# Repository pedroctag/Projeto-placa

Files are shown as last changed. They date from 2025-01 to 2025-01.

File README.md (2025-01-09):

# PBLE02 - Gerenciamento de alarme

Este projeto foi feito por [Lucas Moura](https://github.com/lucaslpmoura), [Lucas Romualdo](https://github.com/ROMUALDO-TXT) e [Pedro Coelho Tagliaferro](https://github.com/pedroctag) para a disciplina PBLE02 - *Board Bring-up e Validação de Projetos*, na Universidade de Federal de Itajubá, em 2023/1.

O projeto consiste em um mockup de sistema de validação de alarmes, utilizando o microprocessador PIC18F4550 como base. 

## Dependências 
- [Kicad](https://www.kicad.org)
- [xc8](https://www.microchip.com/en-us/tools-resources/develop/mplab-xc-compilers)

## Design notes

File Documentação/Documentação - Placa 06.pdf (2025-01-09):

PBLE02

Board Bring-Up e Validação de Protótipos

Documentação de Hardware/Software

Grupo 06

### 1. IDENTIFICAÇÃO DOS INTEGRANTES

Lucas Louzada Paganoto Moura – 2022006102

Lucas Romualdo Lemos – 2021017077

Pedro Coelho Talgiaferro – 2021007929

## SUMÁRIO

### 2. INTRODUÇÃO

O objetivo deste projeto foi a aplicação componentes de hardware e o

desenvolvimento de software para uma placa de circuito impresso

desenvolvida por alunos da disciplina PBLE01.

A placa constitui um mockup de um sistema de gerenciamento de

alarme. O usuário pode definir os níveis de alarmes a serem gerenciados, e

a placa alerta quando os limiares previamente escolhidos são atingidos.

Para o hardware, foi seguido os esquemáticos e componentes

especificados pelo projeto inicial, porém alterações tiveram de ser feitas

devido a limitações na disponibilidade de componentes e erros de projeto.

O software foi desenvolvido na linguagem C, utilizando o compilador

XC8. Foram desenvolvidas bibliotecas próprias a fim de se obter o resultado

esperado, em conjunto com outras fornecidas pelo Profº. Rodrigo Almeida.

A seguir serão descritas a mudanças em hardware realizadas, o digrama

UML das bibliotecas criadas e o diagrama de estados utilizado pela lógica

interna da placa

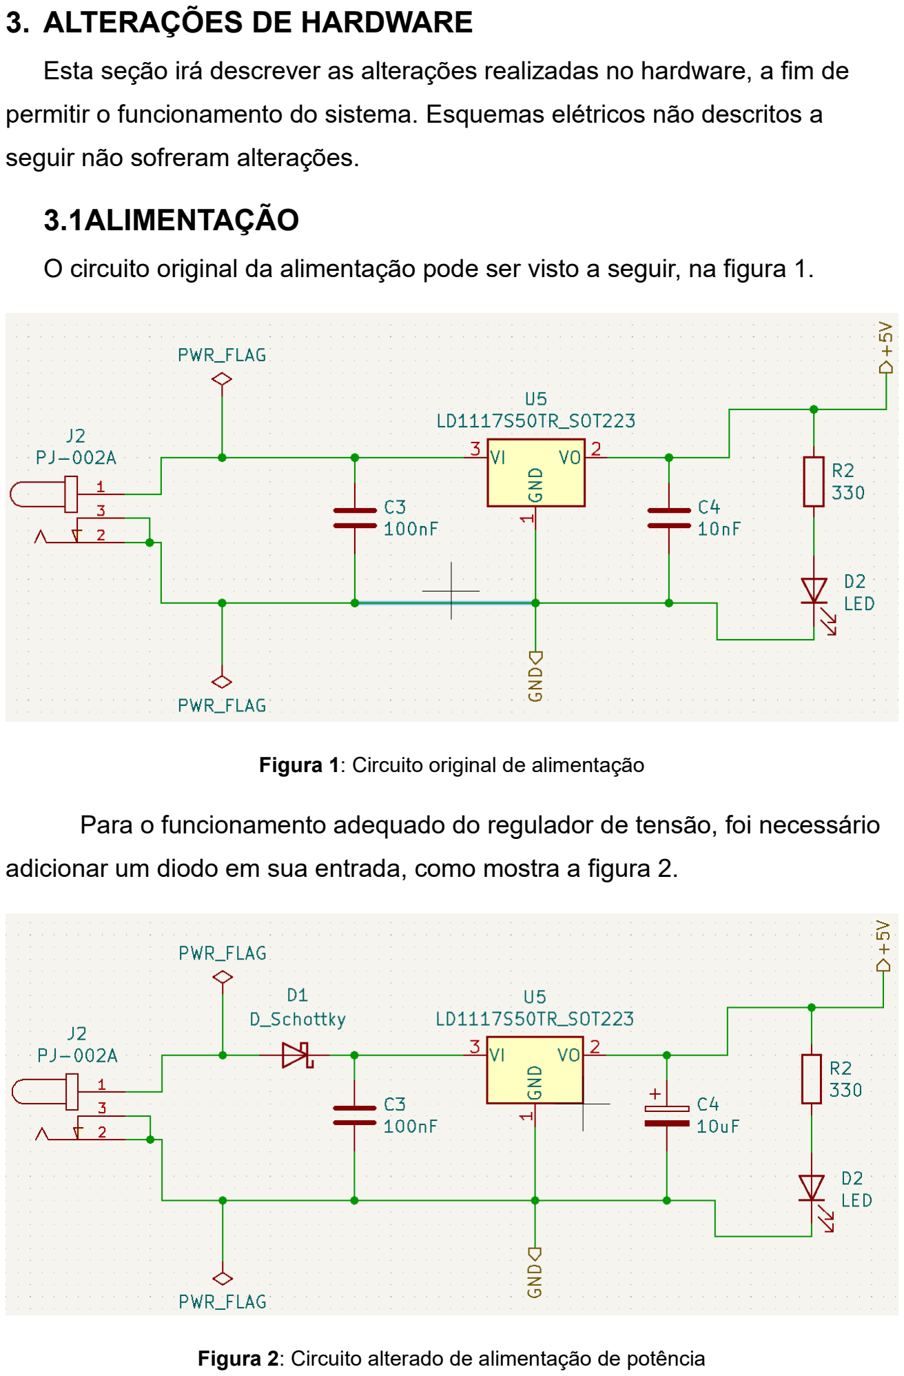
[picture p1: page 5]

### 3. ALTERAÇÕES DE HARDWARE

Esta seção irá descrever as alterações realizadas no hardware, a fim de

permitir o funcionamento do sistema. Esquemas elétricos não descritos a

seguir não sofreram alterações.

3.1ALIMENTAÇÃO

O circuito original da alimentação pode ser visto a seguir, na figura 1.

Figura 1: Circuito original de alimentação

Para o funcionamento adequado do regulador de tensão, foi necessário

adicionar um diodo em sua entrada, como mostra a figura 2.

Figura 2: Circuito alterado de alimentação de potência

### 3.2 LEDs DE SINALIZAÇÃO

O esquemático original dos leds pode ser visto a seguir, na figura 3.

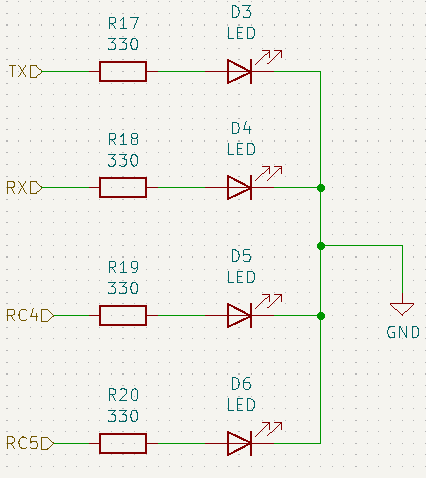
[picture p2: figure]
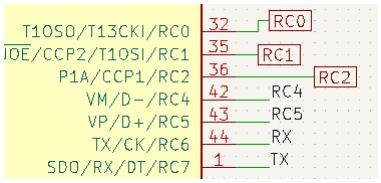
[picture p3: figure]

Figura 3: Leds sinalizadores e seus pinos conectados originalmente

Os pinos escolhidos originalmente para os leds sinalizadores (conexões

RC4 e RC5 nos pinos 42 e 43) só podem operar como entradas digitais. Na

configuração de catodo comum, os leds não conseguem operar. Assim optou-

se por trocar os pinos dos leds para 35 e 36, como mostra a figura 4.

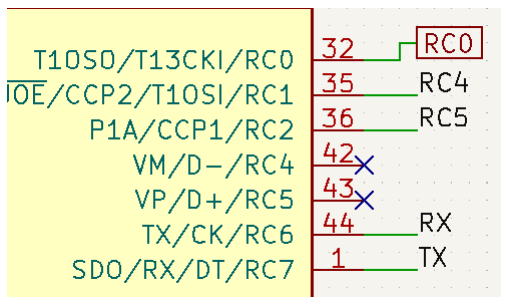
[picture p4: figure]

Figura 4: Pinagem atualizada dos leds

### 3.3 SAÍDA ANALÓGICA

No projeto original, a saída original possuía um filtro passa-baixa

simples, como mostra a figura 5.

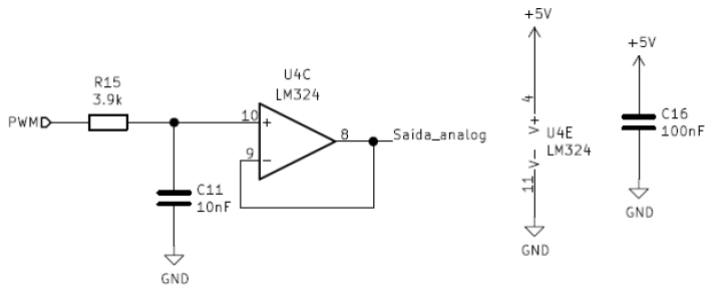
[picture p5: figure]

Figura 5: Saída analógica com filtro passa-baixa

A fim de melhorar a robustez do projeto, o filtro de saída foi alterado para

um Butterworth, adicionando mais um resistor e capacitor, como mostra a figura

6.

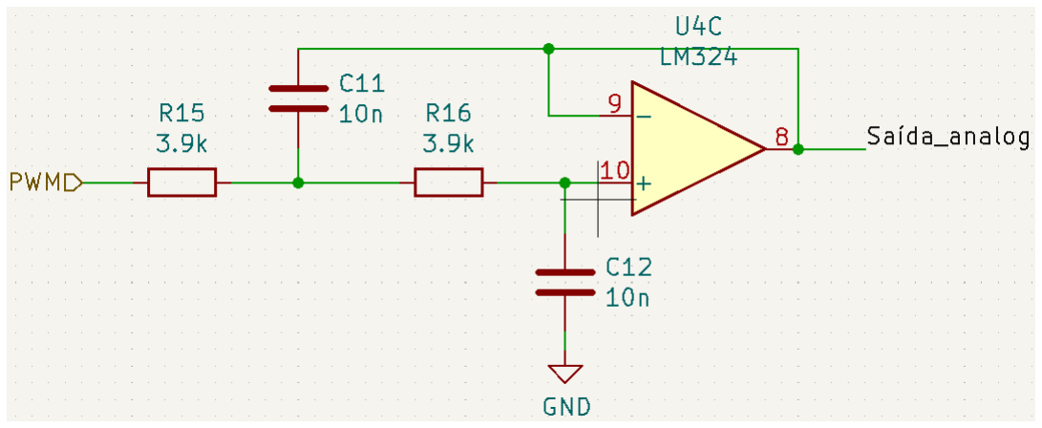
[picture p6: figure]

Figura 6: Filtro Butterworth implementado na saída analógica

### 3.4 VISOR LCD

A pinagem original do visor LCD é como mostra na figura 7.

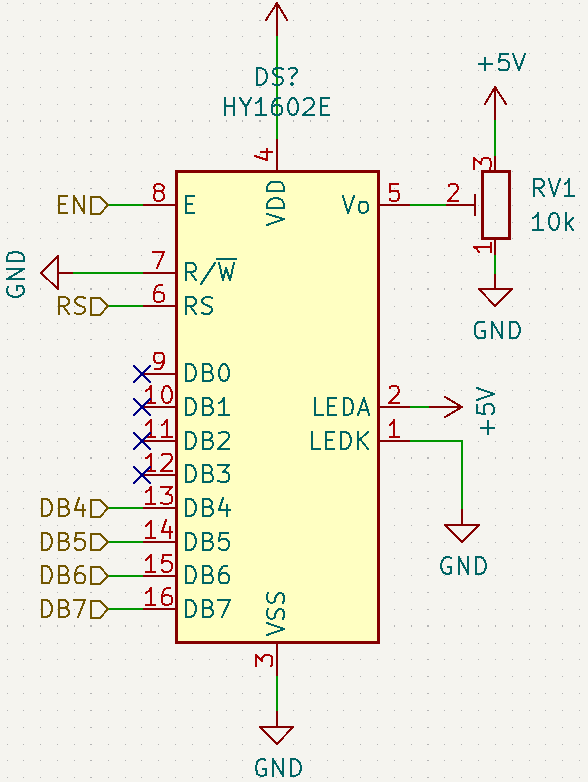
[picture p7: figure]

Figura 7: Pinagem original do LCD

Como o projeto original foi feito pensando com um outro modelo de LCD, foi necessária alteração da pinagem do LCD, em relação ao microprocessador. A pinagem alterada é vista na figura 8.

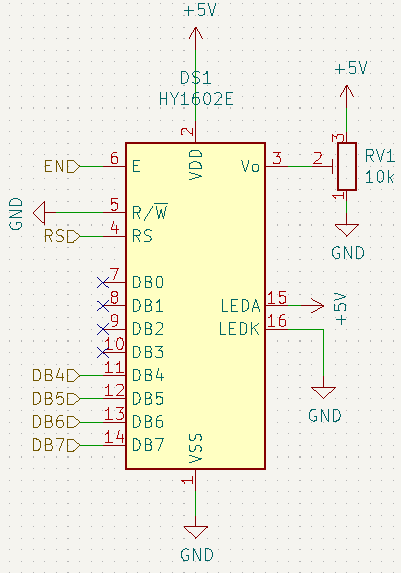
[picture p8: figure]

Figura 8: Pinagem alterada do LCD

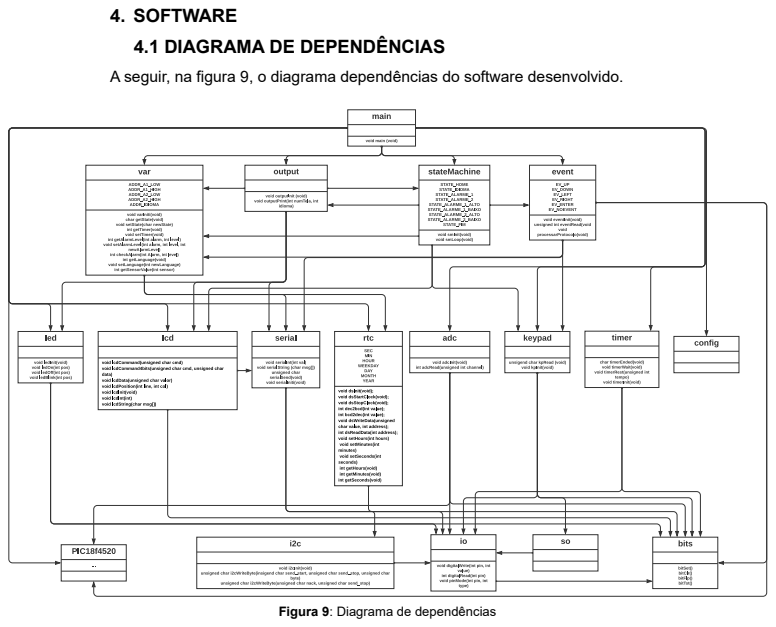
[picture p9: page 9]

4. SOFTWARE
4.1 DIAGRAMA DE DEPENDÊNCIAS

A seguir, na figura 9, o diagrama dependências do software desenvolvido.

Figura 9: Diagrama de dependências

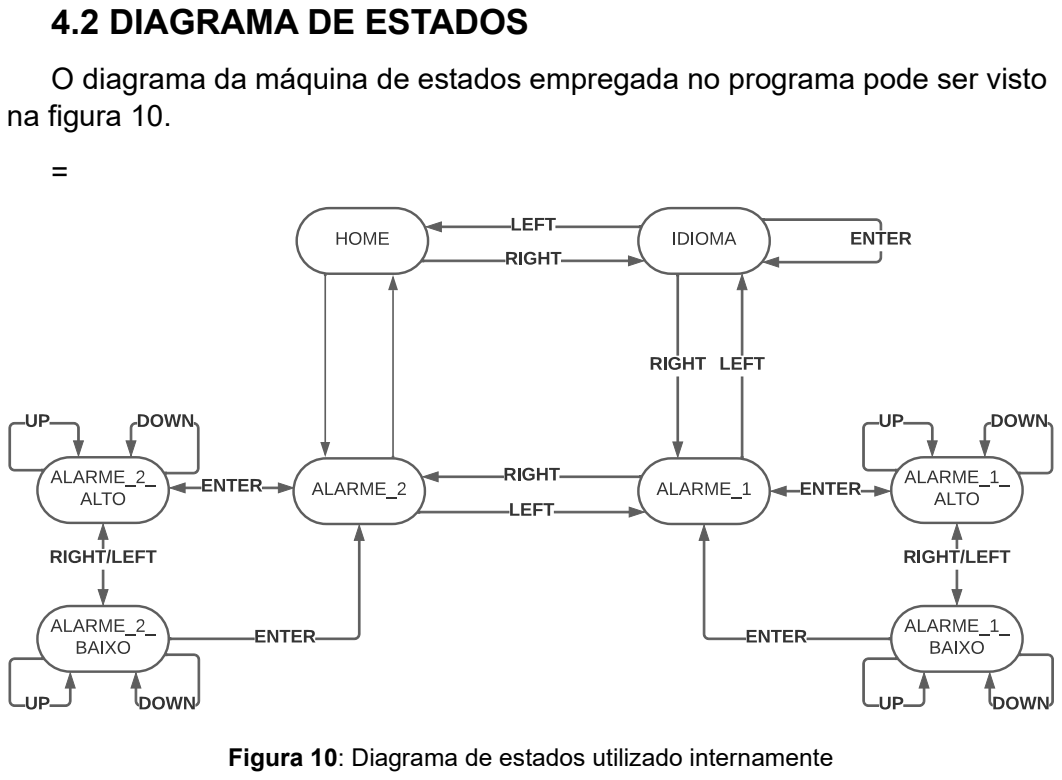
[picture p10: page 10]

4.2 DIAGRAMA DE ESTADOS

O diagrama da máquina de estados empregada no programa pode ser visto
na figura 10.

Figura 10: Diagrama de estados utilizado internamente

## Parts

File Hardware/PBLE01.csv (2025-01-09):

Source: | C:\Users\Anderson\Desktop\PBL 2021-20230308T131919Z-001\PBL 2021\G6\Placa\PBLE01.sch
Date: | 08/03/2023 10:38:58
Tool: | Eeschema (6.0.7)
Generator: | C:\Program Files\KiCad\6.0\bin\scripting\plugins/bom_csv_grouped_by_value_with_fp.py
Component Count: | 65
Ref | Qnty | Value | Cmp name | Footprint | Description | Vendor
C1, C2, | 2 | 15pF | C | Capacitor_SMD:C_0805_2012Metric_Pad1.18x1.45mm_HandSolder | Unpolarized capacitor
C3, C6, C13, C14, C15, C16, | 6 | 100nF | C | Capacitor_SMD:C_0805_2012Metric_Pad1.18x1.45mm_HandSolder | Unpolarized capacitor
C4, | 1 | 10uF | CP-Device | SamacSys_Parts:CAPPM3216X180N
C5, | 1 | 220nF | C | Capacitor_SMD:C_0805_2012Metric_Pad1.18x1.45mm_HandSolder | Unpolarized capacitor
C7, C8, | 2 | 22pF | C | Capacitor_SMD:C_0805_2012Metric_Pad1.18x1.45mm_HandSolder | Unpolarized capacitor
C9, C10, | 2 | 10pF | C | Capacitor_SMD:C_0805_2012Metric_Pad1.18x1.45mm_HandSolder | Unpolarized capacitor
C11, C12, | 2 | C | C | Capacitor_SMD:C_0805_2012Metric_Pad1.18x1.45mm_HandSolder | Unpolarized capacitor
D2, D3, D4, D5, D6, | 5 | LED | LED | LED:LTST-C150GKT | Light emitting diode
DS1, | 1 | HY1602E | HY1602E | Display:HY1602E | LCD 16x2 Alphanumeric 16pin Blue/Yellow/Green Backlight, 8bit parallel, 5V VDD
J1, | 1 | ICSP | Conn_01x06_Male | Connector_PinHeader_2.54mm:PinHeader_1x06_P2.54mm_Vertical | Generic connector, single row, 01x06, script generated (kicad-library-utils/schlib/autogen/connector/)
J2, | 1 | PJ-002A | PJ-002A | PJ-002A:CUI_PJ-002A
J3, | 1 | USB | 897-43-004-90-000000 | SamacSys_Parts:8974300490000000
J4, J5, | 2 | Screw_Terminal_01x02 | Screw_Terminal_01x02 | TerminalBlock_MetzConnect:TerminalBlock_MetzConnect_Type011_RT05502HBWC_1x02_P5.00mm_Horizontal | Generic screw terminal, single row, 01x02, script generated (kicad-library-utils/schlib/autogen/connector/)
J6, | 1 | Conn_01x03_Male | Conn_01x03_Male | Connector_PinHeader_2.54mm:PinHeader_1x03_P2.54mm_Vertical | Generic connector, single row, 01x03, script generated (kicad-library-utils/schlib/autogen/connector/)
J7, | 1 | Conn_01x14_Female | Conn_01x14_Female | Connector_PinSocket_2.54mm:PinSocket_1x14_P2.54mm_Vertical | Generic connector, single row, 01x14, script generated (kicad-library-utils/schlib/autogen/connector/)
R1, R4, R5, R6, | 4 | 10k | R | Resistor_SMD:R_0805_2012Metric_Pad1.20x1.40mm_HandSolder | Resistor
R2, R7, R8, R11, R12, R17, R18, R19, R20, | 9 | 330 | R | Resistor_SMD:R_0805_2012Metric_Pad1.20x1.40mm_HandSolder | Resistor
R9, R10, R13, R14, | 4 | 1k | R | Resistor_SMD:R_0805_2012Metric_Pad1.20x1.40mm_HandSolder | Resistor
R15, R16, | 2 | R | R | Resistor_SMD:R_0805_2012Metric_Pad1.20x1.40mm_HandSolder | Resistor
R21, | 1 | 470 | R | Resistor_SMD:R_0805_2012Metric_Pad1.20x1.40mm_HandSolder | Resistor
RV1, | 1 | 10k | R_POT_TRIM-Device | Potentiometer_THT:Potentiometer_Bourns_3296W_Vertical
RV2, | 1 | R_POT | R_POT-Device | SamacSys_Parts:P160KN0QC15B100K
SW1, SW2, SW3, SW4, SW5, SW6, | 6 | 1825910-6 | 1825910-6 | Chave TÃ¡ctil:SW_1825910-6-4
U1, | 1 | PIC18F4550-IPT | PIC18F4550-IPT | Package_QFP:TQFP-44_10x10mm_P0.8mm | 32K Flash, 2K SRAM, 256 EEPROM, USB, nanoWatt XLP, TQFP44
U2, | 1 | MCP2200-I-SO | MCP2200-I-SO | Package_SO:SOIC-20W_7.5x12.8mm_P1.27mm | USB 2.0 to UART Protocol Converter with GPIO, SOIC-20
U3, | 1 | MCP7940N-xSN | MCP7940N-xSN-Timer | SamacSys_Parts:SOIC127P600X175-8N
U4, | 1 | LM324 | LM324 | SamacSys_Parts:SOIC127P600X175-14N | Low-Power, Quad-Operational Amplifiers, DIP-14/SOIC-14/SSOP-14
U5, | 1 | LD1117S50TR_SOT223 | LD1117S50TR_SOT223 | Package_TO_SOT_SMD:SOT-223-3_TabPin2 | 800mA Fixed Low Drop Positive Voltage Regulator, Fixed Output 5.0V, SOT-223
Y1, | 1 | 20MHz | Crystal | Crystal:Crystal_HC49-4H_Vertical | Two pin crystal
Y2, | 1 | 12MHz | Crystal | Crystal:Crystal_HC49-4H_Vertical | Two pin crystal
Y3, | 1 | 32.768kHz | Crystal | SamacSys_Parts:XTAL_AB38T-32.768KHZ | Two pin crystal

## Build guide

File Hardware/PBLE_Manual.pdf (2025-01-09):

## PBLE01 Co-projeto de produtos eletrônicos

### Manual

Grupo 6

________________________________________________________________________________

## Sumário

________________________________________________________________________________

## 1 Identificação dos integrantes

André Luís Oliveira de Almeida – 2019008624
João Roberto da Silva Couto - 2018000944 Lucas Ferreira Machado - 2019000537

________________________________________________________________________________

## 2 Introdução

O objetivo da disciplina era certamente nos incluir no ramo do mercado de

trabalho para projetos, protótipos e lançamentos de PCIs (placas de circuito impresso) e

ideias correlacionadas, por promover uma experiência de mercado de trabalho, com o maior

número possível de detalhes ao ponto que a disciplina em si não ensina quase nada novo,

pois foi visto o que se requere no projeto em períodos anteriores.

As principais atividades a serem desenvolvidas durante o transcorrer da disciplina

são o projeto da placa de circuito impresso, o desenvolvimento de programa embarcado de

validação e a elaboração da documentação de projeto, etapas que não devem seguir um

planejamento de inícios e términos, com etapas sendo discutidas e aprimoradas ao mesmo

tempo, como se observa no desenho abaixo:

Figura 1 - Diagrama de avanço de tarefas

A etapa de projeto da placa de circuito ainda pode ser subdividida nas etapas de

elaboração do esquema elétrico e de elaboração da PCI.

a documentação de projeto, a etapa que aqui vos instrui, a ser desenvolvido consiste

em um manual a partir do qual é possível confeccionar e validar a placa de circuito impresso

projetada. Para tanto, tal documento deve pormenorizar características do circuito elabo-

rado, como seu esquema elétrico, suas características elétricas, os passos para sua vali-

dação bem como a relação de seus componentes e os fornecedores para estes.

Dizem que o engenheiro é aquele que aplica os conhecimentos dos cientistas, então

este projeto, e consequentemente esta disciplina é a oportunidade perfeita para isso.

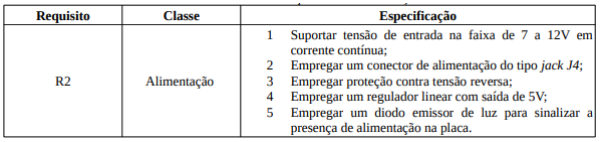
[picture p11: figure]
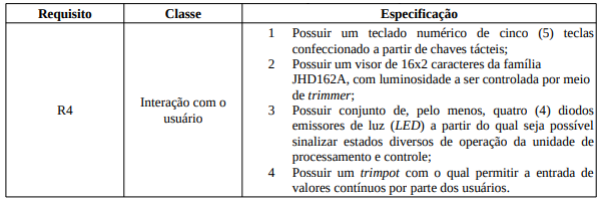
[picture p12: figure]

________________________________________________________________________________

## 3 Esquema elétrico

A atividade de elaboração de esquema elétrico consiste em desenvolver a repre-

sentação do circuito eletroeletrônicos relativo à placa de circuito impresso em projeto.

Essa atividade costuma ser realizada por meio de ferramentas de desenvolvimento gráfi-

cas. Em linhas gerais, por meio dessas ferramentas, são elencados (e representados) os

componentes eletrônicos discretos a fazerem parte da placa de circuito impresso em pro-

jeto e a interconexão entre eles.

## 3.1 Requisitos

________________________________________________________________________________

________________________________________________________________________________

## 3.2 Circuito

O dispositivo almejado deve permitir, como principal meta, a interação entre diversas

entradas e saídas com a unidade de processamento e os subcircuitos necessários para a

efetivar a requisição do usuário.

Dentre entradas, algumas diretamente vindas do usuário (como o teclado), outras

pré-definidas por estes (as entradas analógicas), outras vindas de terceiros (diferenciais) e

ainda uma entrada do próprio dispositivo (RTC).

Dentre saídas, existem as que tanto visam informar o usuário (sinais de estados e

LCD) quanto exportar um resultado (saída analógica).

Figura 2 - representação em blocos funcionais do circuito

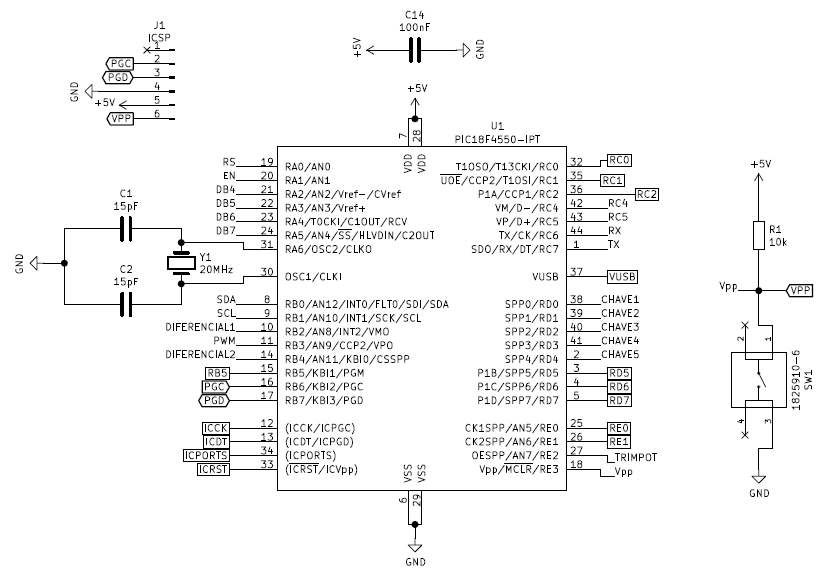
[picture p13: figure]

________________________________________________________________________________

## 3.3 Esquemas elétricos

### 3.3.1 Unidade de processamento

A unidade de processamento é o “cérebro” do circuito, responsável não só pelos

cálculos necessários, mas também pelo ritmo de todo o sistema. Desde as etapas de fun-

cionamento de uma requisição até a forma de como serão demonstrados, e quando serão

atualizados, os resultados da devida requisição. Confira abaixo o esquema elétrico

Figura 3- Esquema elétrico da unidade de processamento

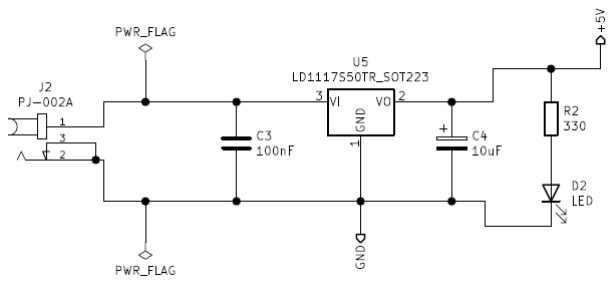
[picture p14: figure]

________________________________________________________________________________

### 3.3.2 Alimentação

A subdivisão da alimentação é responsável por suprir devidamente a demanda

energética do sistema, reduzindo a tensão da fonte de alimentação externa para o nível

necessário para o projeto em questão. Confira abaixo o esquema elétrico.

Figura 4- Esquema elétrico do subcircuito de alimentação

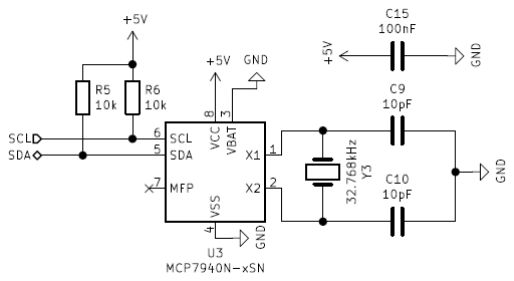
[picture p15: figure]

________________________________________________________________________________

### 3.3.3 Relógio de Tempo Real

Esta subdivisão baseia-se em comunicação com o microcontrolador através do pro-

tocolo I2C e pode fornecer informações de data, hora, ano e afins, assim como pode tam-

bém receber dados do PIC. Confira abaixo seu esquema elétrico.

Figura 5- Esquema elétrico do relógio de tempo real

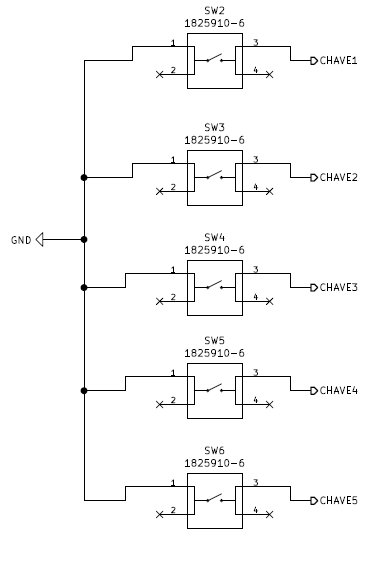
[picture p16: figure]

________________________________________________________________________________

### 3.3.4 Teclado

O teclado, parte de uso exclusivo do usuário para com o usuário, é constituído por

5 botões e permitem que o usuário forneça valores digitais para o sistema, assim como

configurar o que deve aparecer no LCD, que dado específico planeja obter, etc. Confira

abaixo seu esquema elétrico.

Figura 6- Esquema elétrico do Teclado

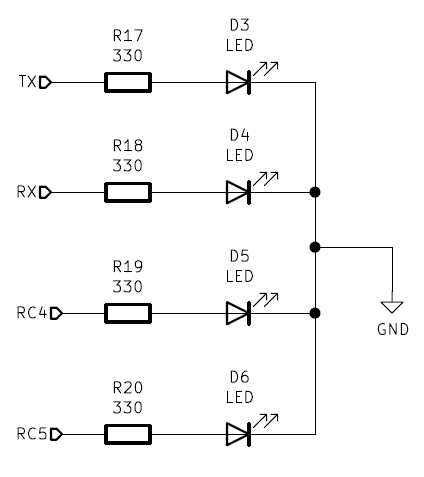
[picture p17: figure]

________________________________________________________________________________

### 3.3.5 Sinalização

A sinalização para o usuário é formada por um conjunto de 4 leds e tem a função de

fornecer uma sinalização luminosa sobre determinados pinos do microcontrolador. Confira

abaixo seu esquema elétrico.

Figura 7- Esquema elétrico da sinalização luminosa

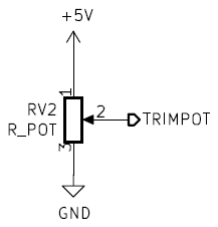
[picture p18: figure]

________________________________________________________________________________

### 3.3.6 Entrada Analógica

Esta consiste em apenas 1 trimpot e tem a função de fornecer um valor analógico

para o microcontrolador. Confira abaixo seu Esquema elétrico.

Figura 8- Esquema elétrico da entrada analógica

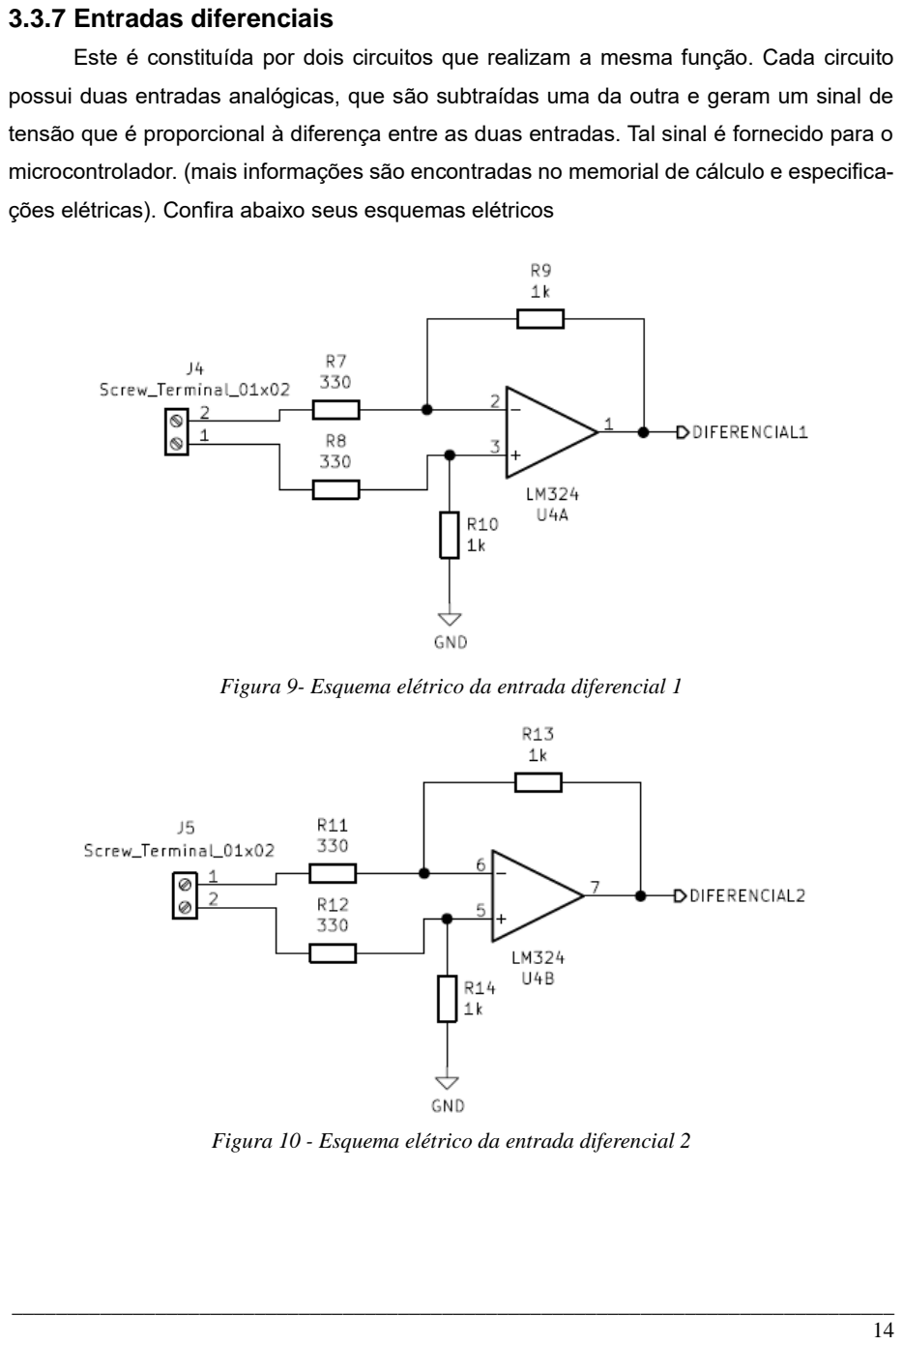
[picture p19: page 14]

________________________________________________________________________________

### 3.3.7 Entradas diferenciais

Este é constituída por dois circuitos que realizam a mesma função. Cada circuito

possui duas entradas analógicas, que são subtraídas uma da outra e geram um sinal de

tensão que é proporcional à diferença entre as duas entradas. Tal sinal é fornecido para o

microcontrolador. (mais informações são encontradas no memorial de cálculo e especifica-

ções elétricas). Confira abaixo seus esquemas elétricos

Figura 9- Esquema elétrico da entrada diferencial 1

Figura 10 - Esquema elétrico da entrada diferencial 2

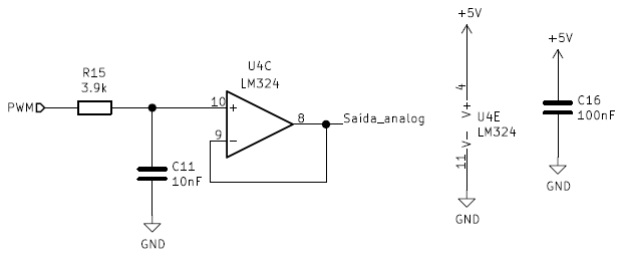
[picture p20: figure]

________________________________________________________________________________

### 3.3.8 Saída Analógica

Essa parte é formada por um filtro passa-baixa e tem a função de fornecer um nível

de tensão para o usuário. Esse nível de tensão é gerado a partir de uma saída PWM do

microcontrolador. Confira abaixo seu esquema elétrico.

Figura 11- Esquema elétrico da saída analógica

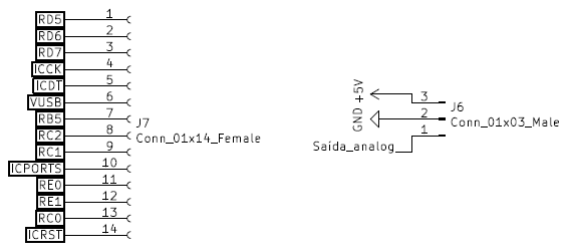
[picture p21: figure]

________________________________________________________________________________

### 3.3.9 Barras de expansão

uma barra contempla todos os pinos do microcontrolador que não estão sendo usa-

dos. A outra barra contempla os sinais de alimentação do circuito e a saída analógica que

foi mostrada na saída analógica. Confira abaixo seu esquema elétrico.

Figura 12- esquema elétrico das barras de expansão

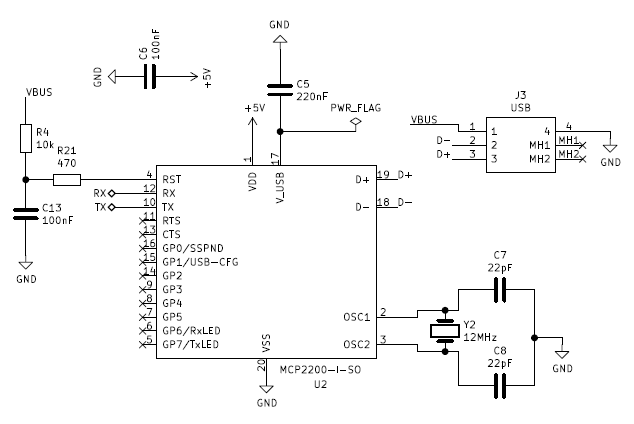
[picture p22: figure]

________________________________________________________________________________

### 3.3.10 Comunicação serial

Esse sub-circuito é principalmente constituído por um conversor USB-serial e um

conector USB. Ele tem a função de estabelecer a comunicação entre o microcontrolador

e, por exemplo, um computador que esteja conectado à placa através de um cabo USB.

Confira seu esquema elétrico na imagem abaixo.

Figura 13- Esquema elétrico do subcircuito de comunicação serial

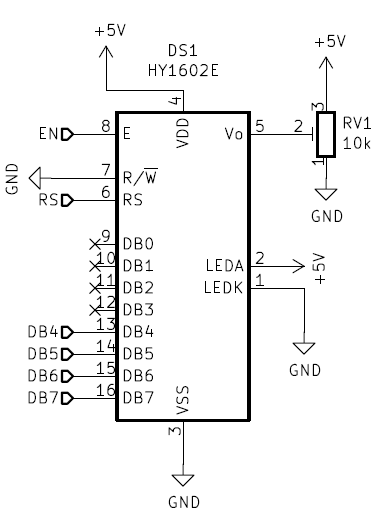
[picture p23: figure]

________________________________________________________________________________

### 3.3.11 Visor LCD

Essa parte é constituída por um visor de cristal líquido e um trimmer. Tem o objetivo

de fornecer informações em formato de texto para o usuário sobre algum estado do sis-

tema. O trimmer serve para alterar o contraste do visor. Confira abaixo seu esquema elé-

trico

Figura 14- Esquema elétrico do visor LCD

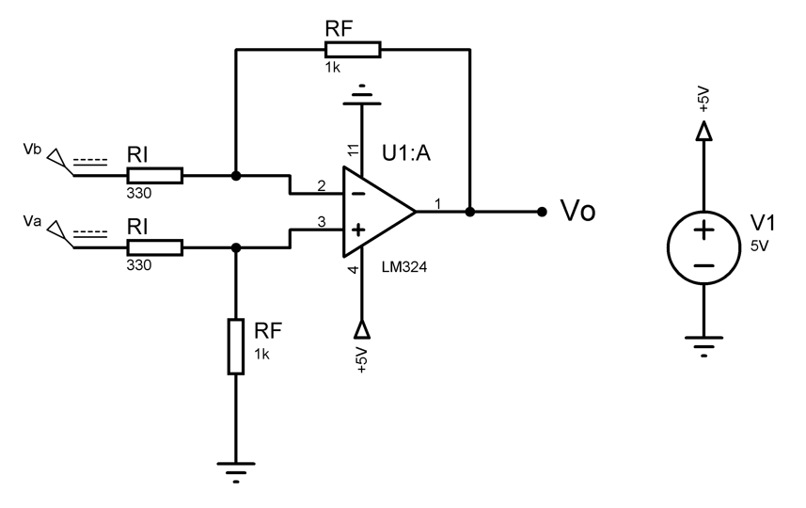
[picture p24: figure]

________________________________________________________________________________

## 3.4 Memorial de cálculos

### 3.4.1 Entradas diferenciais

Ambas entradas diferenciais apresentam o circuito apresentado acima. A equação

para a tensão de saída é mostrada abaixo:

VO =

RF
RI

∗ (VA − VB)

Já que a saída deveria variar de 0 a 3V, o ganho escolhido foi de: RF
RI

=

1000
330 = 3,03

A partir desse ganho, a entrada diferencial (VA − VB) poderia variar de 0 a 1V. Po-

rém, a tensão inferior de saturação do amplificador operacional escolhido é de 0.5V (ca-

racterística inerente ao amplificador), e por causa disso, se a entrada diferencial for menor

do que aproximadamente 0.17V, a saída ficará limitada ao valor de 0.5V, como é mos-

trado a seguir:
VO = 3,03 ∗ (0,17) = 0,51 V

Conclusão:

Para (VA − VB) variando de 0.17V a 1V

VO vai variar de 0.5V a 3V

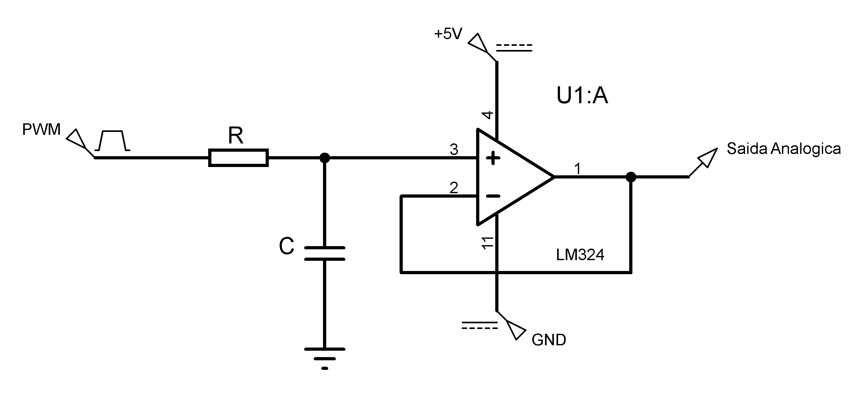
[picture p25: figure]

________________________________________________________________________________

### 3.4.2 Saída Analógica

Projeto do filtro passa-baixa:

A frequência de corte escolhida para o filtro foi de 4 kHz. Para descobrir a frequên-

cia do PWM, foi usada a seguinte relação (onde fC é a frequência de corte e K é uma

constante):
fPWM = K ∗ fC

Escolhendo uma constante K=25, com o objetivo de gerar uma frequência bem alta

para o PWM, chegou-se ao seguinte resultado:
fPWM = K ∗ fC ⇔ fPWM = 25 ∗ 4000 ⇔ fPWM = 100 kHz

A seguir, foram calculados os valores de R e C:

R ∗ C =

1
2 ∗ π ∗ fC

⇔ R ∗ C = 39,78 ∗ 10⁻⁶

Escolhendo um R = 3,9kΩ (valor comercial), foi encontrado o valor de C:

C =

39,78 ∗ 10⁻⁶
3900

⇔ C = 10,2 ∗ 10⁻⁹

Logo, os valores finais comerciais escolhidos e a frequência do PWM são resumi-

dos abaixo:
R = 3, 9 kΩ

C = 10 nF

fPWM = 100 kHz

________________________________________________________________________________

## 3.5 Relatório de verificação de erros de projeto

O relatório de erros do esquema elétrico não apresentou nenhum aviso.

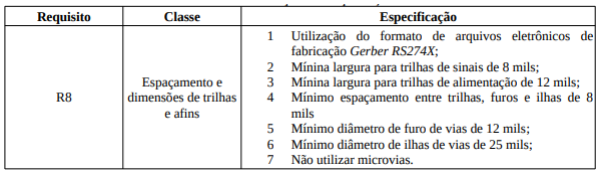
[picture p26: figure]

________________________________________________________________________________

## 4 Placa de circuito impresso

O projeto da placa de circuito impresso se trata de especificar como deve ocorrer a

transposição do esquema elétrico desenvolvido para uma PCI real. Nesta etapa, os com-

ponentes que fazem parte do circuito são associados às pegadas (footprints), e suas in-

terconexões, às trilhas de sinais. Ainda nesta etapa, é também produzida uma lista de

compra para os componentes eletroeletrônicos que fazem parte da placa de circuito im-

presso projetada.

## 4.1 Requisitos

________________________________________________________________________________

## 4.2 Desenho da placa de circuito impresso

Figura 15- Desenho da PCI

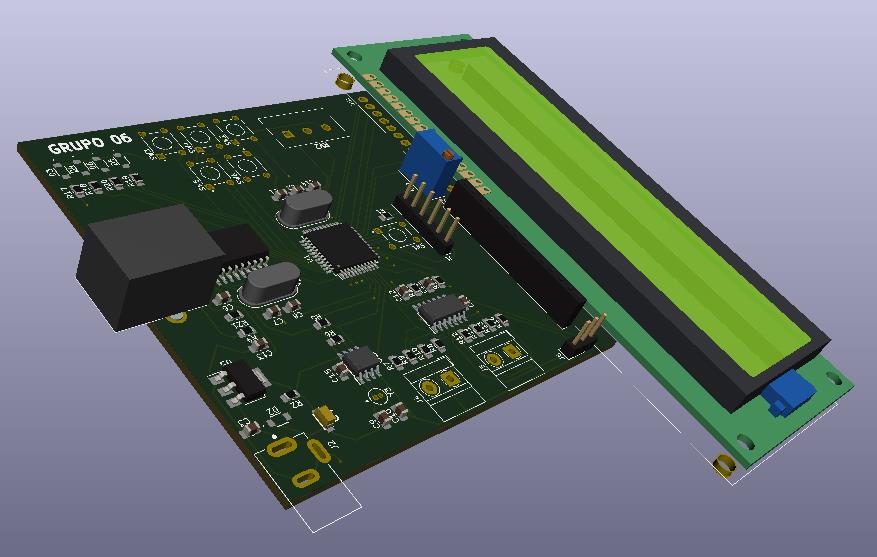
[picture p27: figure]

________________________________________________________________________________

## 4.3 Visão tridimensional do circuito projetado

Figura 16- Visão tridimensional da PCI

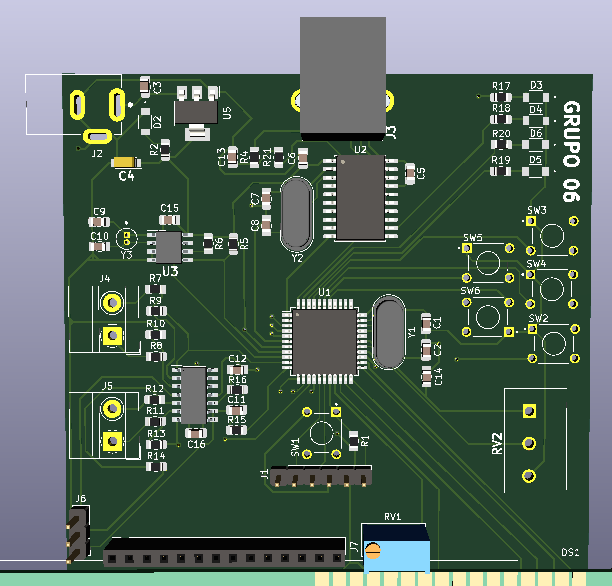
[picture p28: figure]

________________________________________________________________________________

Figura 17- Visão da parte frontal da PCI

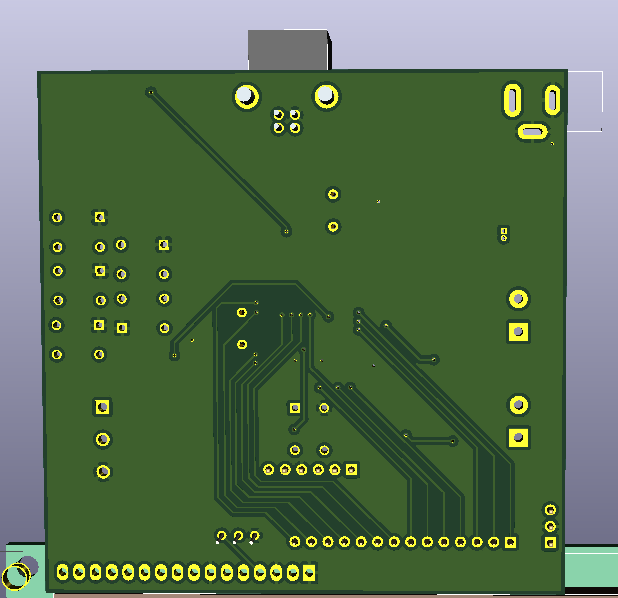
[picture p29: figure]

________________________________________________________________________________

Figura 18- Visão traseira da PCI

________________________________________________________________________________

## 4.4 Relatório de verificação de erros de projeto

** Drc report for C:\Users\Lucas F. Machado\Desktop\PBLE01\PBLE01_Grupo06\PBLE01.kicad_pcb **

** Created on **

** Found 4 DRC errors **

ErrType(19): Ilha muito próxima a ilha

@(115,570 mm, 71,942 mm): Ilha 1 de Y3 em Todas as camadas de cobre

@(115,570 mm, 73,042 mm): Ilha 2 de Y3 em Todas as camadas de cobre

ErrType(45): Sobreposição de pátios

@(147,053 mm, 56,363 mm): Footprint J3 em F.Cu

@(142,314 mm, 60,325 mm): Footprint C6 em F.Cu

ErrType(45): Sobreposição de pátios

@(147,053 mm, 56,363 mm): Footprint J3 em F.Cu

@(138,633 mm, 60,198 mm): Footprint R21 em F.Cu

ErrType(45): Sobreposição de pátios

@(176,847 mm, 98,770 mm): Footprint RV2 em F.Cu

@(161,064 mm, 93,467 mm): Footprint C14 em F.Cu

** Found 0 unconnected pads **

** End of Report **

________________________________________________________________________________

## 5 Especificações elétricas

## 5.1 Níveis de alimentação suportados

A placa suporta fonte de corrente contínua externa que seja entre 7V a 15V.

Tensões inferiores a 7V também podem ser aplicadas, porém não é recomendado,

pois o sistema pode não operar da forma correta.

## 5.2 Faixa de níveis de consumo estimadas

Estamos usando 22 portas do microcontrolador para acionar saídas e ler entradas.

Como cada porta tem a capacidade de drenar ou fornecer 20mA de corrente, então, con-

siderando o pior caso (onde todas as portas estão operando com o máximo de sua capa-

cidade e ao mesmo tempo), o sistema vai consumir aproximadamente:

22 portas x 20mA = 440mA

## 5.3 Correntes e tensões máximas de entrada

Entradas Diferenciais → 0 a 32V em cada entrada de cada par diferencial.

## 5.4 Correntes e tensões máximas de saída

Saída analógica → 0,5V a 4,5V (é limitada pela saída PWM).

________________________________________________________________________________

## 6 Programa embarcado de validação

Na etapa de desenvolvimento do programa embarcado, é desenvolvido um se-

quenciamento de ações mínimo a ser utilizado exclusivamente para se testar as funciona-

lidades básicas de componentes do circuito impresso projetado, como, por exemplo, para

se verificar se uma unidade de processamento é capaz de detectar e identificar interações

com demais componentes do circuito. Esse programa embarcado não corresponde ao

programa final de aplicação da placa desenvolvida, mas apenas a um subproduto de pro-

jeto utilizado exclusivamente para se realizar certas validações de projeto.

________________________________________________________________________________

## 7 Montagem

## 7.1 Lista de compras

ITEM | QUANTIDADE | FABRICANTE | PART NUMBER
Amplificador Operacional | 3 | On Semi | LM324DG
Capacitor 100nF | 6 | Diversos | 445-175390-1-ND
Capacitor 10nF | 1 | Diversos | C321C103J3G5TA- ND
Capacitor 10pF | 2 | Diversos | 399-7815-2-ND
Capacitor 10uF | 2 | Diversos | 493-1057-ND
Capacitor 15pF | 2 | Diversos | 399-4152-ND
Capacitor 220nF | 1 | Diversos | C356C224K1G5TA- ND
Capacitor 22pF | 2 | Diversos | 399-4220-ND
Chaves tácteis | 6 | TE Connectivity | 1825910-6
Con. Barra de expansão | 1 | TE Connectivity | A31112-ND
Con. Entradas diferenciais | 2 | On Shore Inc. | ED2580-ND
Conector alimentação | 1 | CUI Devices | PJ-002A CUI
Cristal de 12KHZ | 1 | CTS Electronic | CTX1077-ND
Cristal de 20KHZ | 1 | CTS Electronic | CTX1106-ND
Cristal de 32.768KHZ | 1 | ABRACON | 535-9034-ND
LEDs | 5 | Lite On | 160-1169-2-ND
Microprocessador | 1 | Microchip | PIC18F4550-I/PT-ND
Regulador de tensão | 1 | STMicroelectronics | 497-1238-2-ND
Relógio de tempo real | 1 | Microchip | MCP7940N-I/SN
Resistor 10k Ohms | 4 | Diversos | 10KQBK-ND
Resistor 1k Ohms | 4 | Diversos | S1KHTR-ND
Resistor 330 Ohms | 9 | Diversos | 330QBK-ND
Resistor 3k9 Ohms | 1 | Diversos | 3.9KW-2-ND
Resistor 470 Ohms | 1 | Diversos | 470QBK-ND
Transceptor USB-serial | 1 | Microchip | MCP2200-I/SO-ND
Trimmer de 10k | 1 | Bourns Inc | 3296W-1-103RLFTR- ND
Trimpot 10k | 1 | TT Electronics | P160KN- 0QC15B100K
Visor LCD | 1 | Precise | HY1602E

________________________________________________________________________________

## 7.2 Análise de Custos

ID NO E.Elétrico | FORNECEDOR | PREÇO UNITÁRIO
Diversos | Digikey | $1.25
C11 | Digikey | $0.17
Diversos | Digikey | $0.20
Diversos | Digikey | $0.28
Diversos | Digikey | $0.55
C05 | Digikey | $1.67
Diversos | Digikey | $0.20
Diversos | Digikey | $0.11
J7 | Digikey | $0.25
J4, J5 | Digikey | $0.76
J2 | Digikey | $0.60
Y2 | Digikey | $0.36
Y1 | Digikey | $0.36
Y3 | Digikey | $0.32
Diversos | Digikey | $0.31
U1 | Digikey | $6.66
U5 | Digikey | $0.54
U3 | Digikey | $0.80
Diversos | Digikey | $0.10
Diversos | Digikey | $0.10
Diversos | Digikey | $0.10
R15 | Digikey | $0.44
R21 | Digikey | $0.10
U2 | Digikey | $2.16
RV1 | Digikey | $1.81
RV2 | Digikey | $0.43
DS1 | AliExpress | $3.39

Não foi possível comportar a tabela toda no manual, então ela estará em anexo caso necessário.

________________________________________________________________________________

## 8 Anexos

## 8.1 Código-fonte do programa de validação

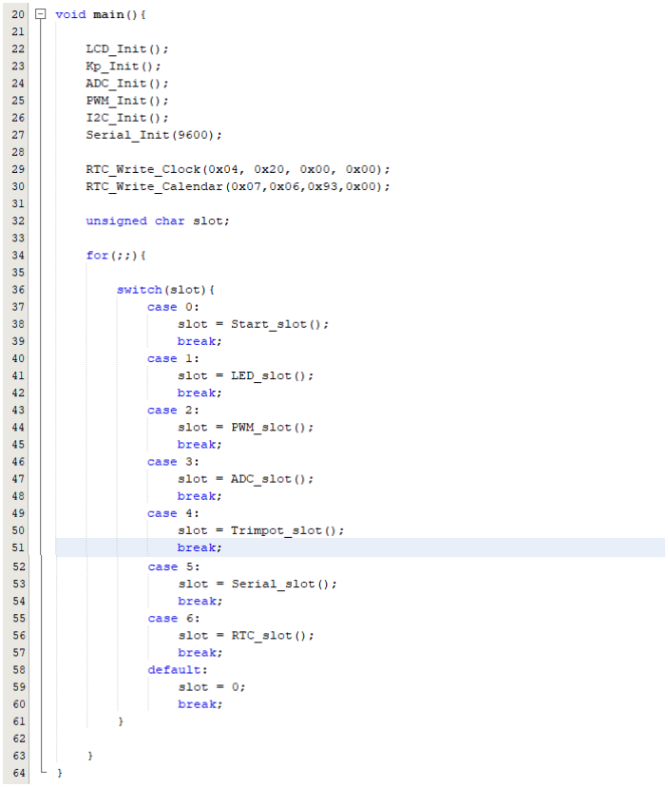
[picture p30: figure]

________________________________________________________________________________

________________________________________________________________________________

________________________________________________________________________________

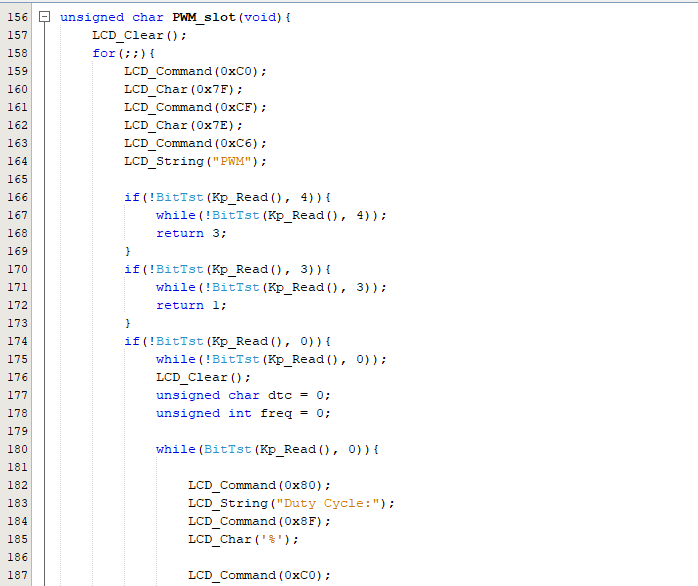
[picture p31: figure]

________________________________________________________________________________

________________________________________________________________________________

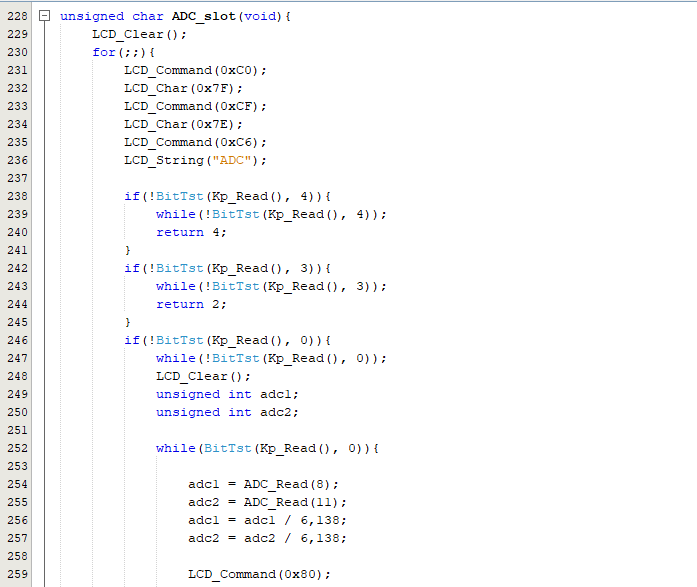
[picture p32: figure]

________________________________________________________________________________

________________________________________________________________________________

________________________________________________________________________________

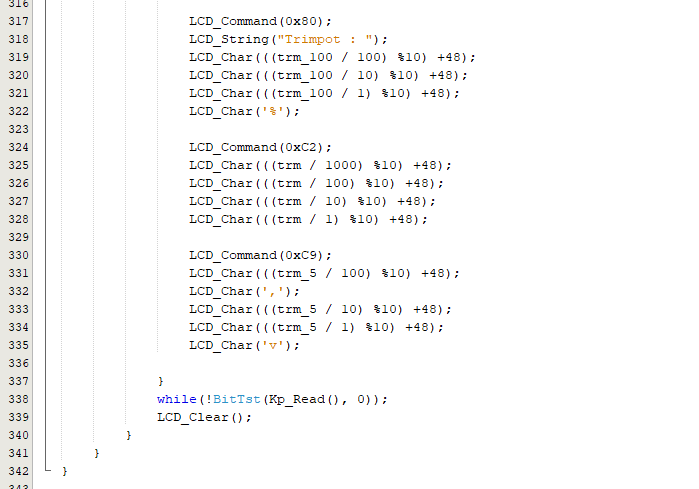
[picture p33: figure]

________________________________________________________________________________

________________________________________________________________________________

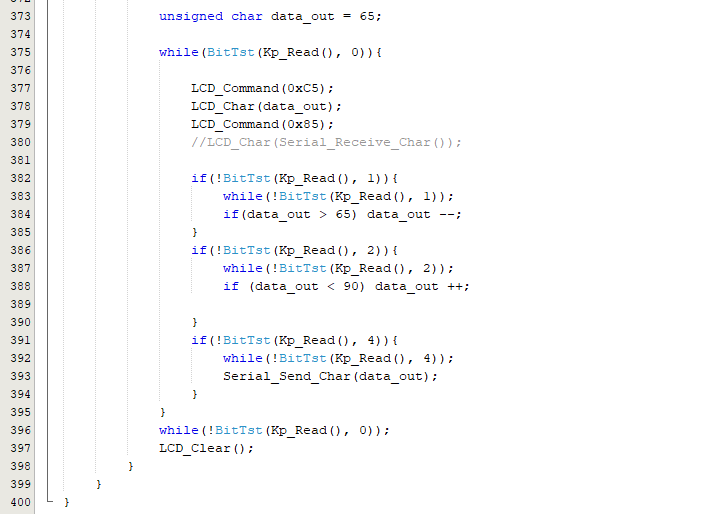
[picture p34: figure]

________________________________________________________________________________

________________________________________________________________________________

________________________________________________________________________________

## 8.2 Programas utilizados

FERRAMENTA | VERSÃO | USO
KiCad | 5.1.10 | Desenvolvimento do esquema elétrico e PCI
Proteus | 8.5 | Simulação do sistema
MPLab | 5.20 | Produção do embarcado de validação

________________________________________________________________________________

## 9 Bibliografia

- Link para cálculo do filtro disponível em: http://ww1.microchip.com/downlo-

ads/en/AppNotes/00538c.pdf (http://ww1.microchip.com/downloads/en/AppNotes/00538c.pdf)

- Aulas e proposta de projeto da disciplina, disponível em: https://sigaa.uni-

fei.edu.br/sigaa/ava/index.jsf (https://sigaa.unifei.edu.br/sigaa/ava/index.jsf)

- Datasheet do amplificador disponível em: https://www.ti.com/pro-

duct/LM324LV?utm_source=supplyframe&utm_medium=SEP&utm_cam-

paign=not_alldatasheet&DCM=yes&dclid=CN73ktOmpfICFUomuQYdCu-

cHcQ (https://www.ti.com/product/LM324LV?DCM=yes&dclid=CN73ktOmpfICFUomuQYdCucHcQ)

- Datasheet do microprocessador disponível em: https://www.micro-

chip.com/en-us/product/PIC18F4550 (https://www.microchip.com/en-us/product/PIC18F4550)

- Datasheet do transceptor disponível em: https://www.microchip.com/en-

us/product/MCP2200 (https://www.microchip.com/en-us/product/MCP2200)

- Datasheet do relógio disponível em: https://www.microchip.com/en-us/pro-

duct/MCP7940N (https://www.microchip.com/en-us/product/MCP7940N)

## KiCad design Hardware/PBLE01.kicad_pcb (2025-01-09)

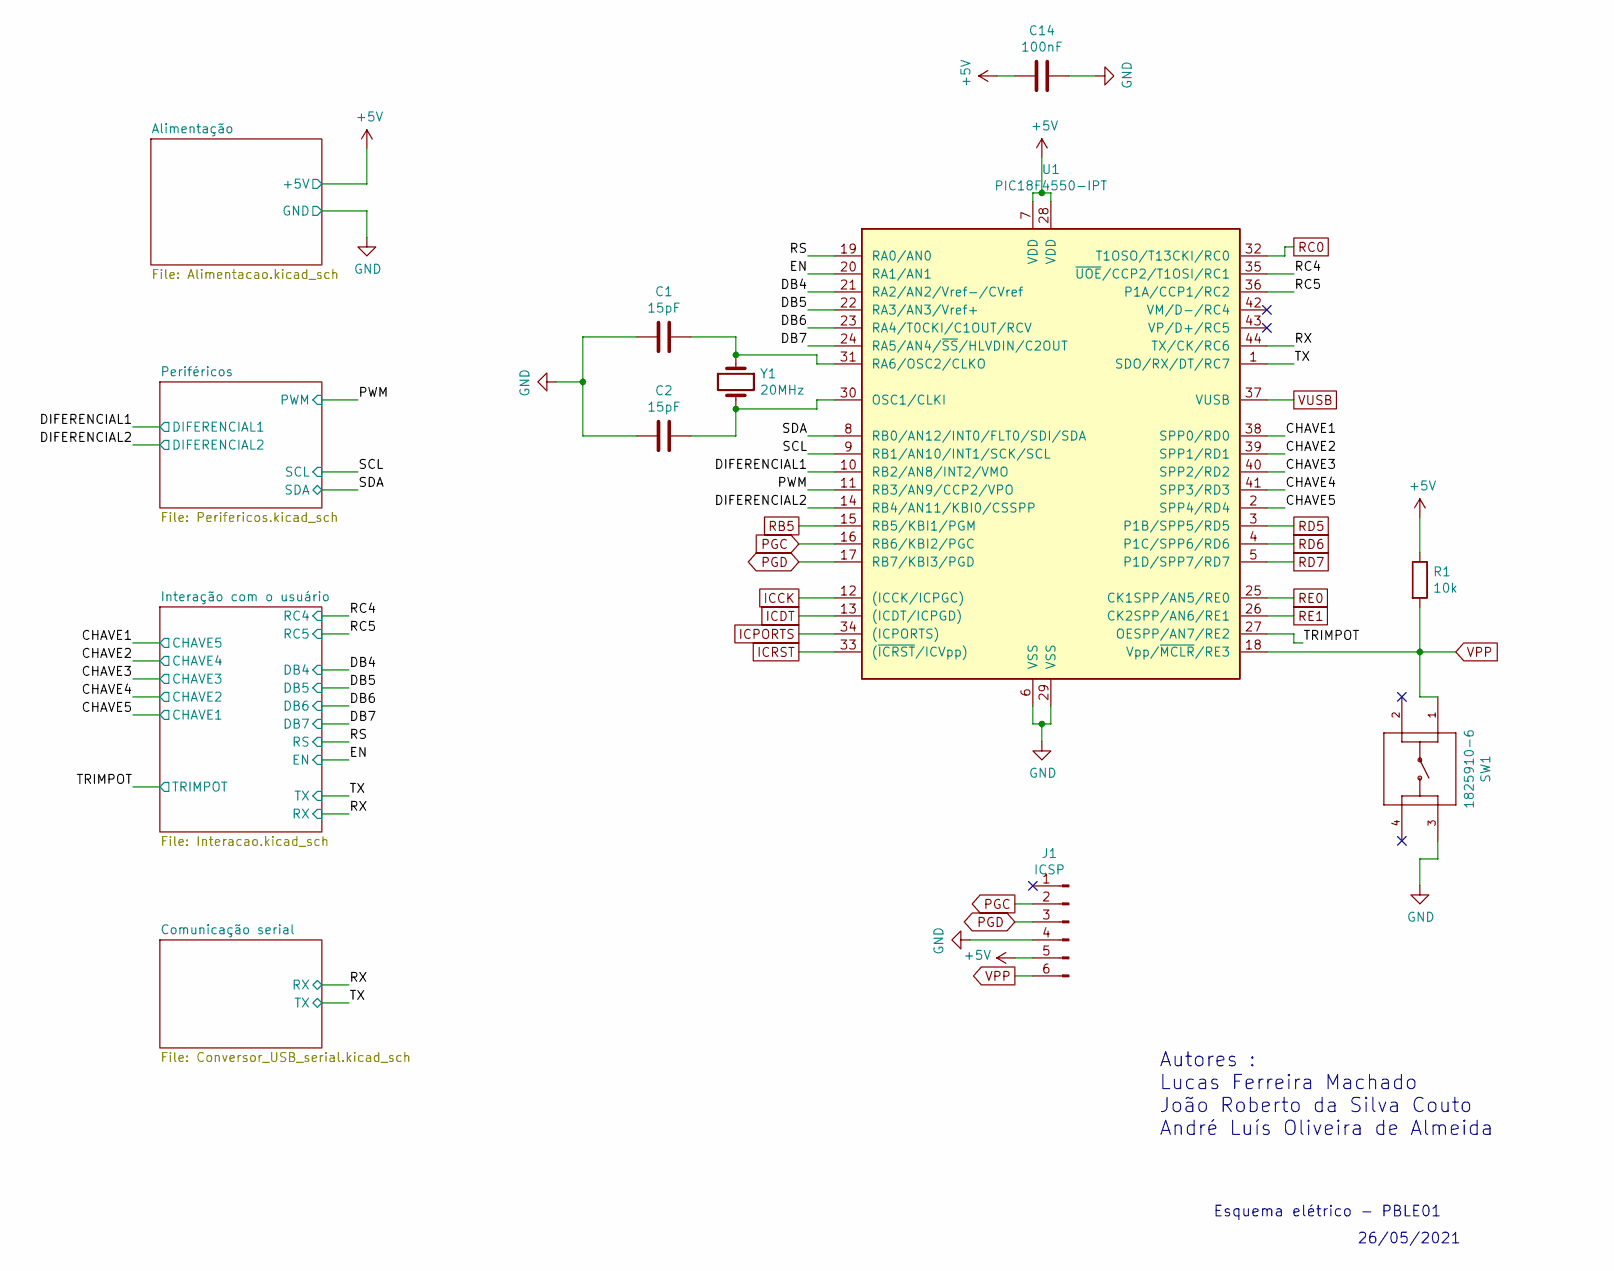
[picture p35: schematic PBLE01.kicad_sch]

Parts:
C1, C2: 15pF; C_0805_2012Metric_Pad1.18x1.45mm_HandSolder
C14: 100nF; C_0805_2012Metric_Pad1.18x1.45mm_HandSolder
J1: ICSP; PinHeader_1x06_P2.54mm_Vertical
R1: 10k; R_0805_2012Metric_Pad1.20x1.40mm_HandSolder
SW1: 1825910-6; SW_1825910-6-4
U1: PIC18F4550-IPT; TQFP-44_10x10mm_P0.8mm
Y1: 20MHz; Crystal_HC49-4H_Vertical

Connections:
+5V: C14.1, J1.5, R1.1, U1.7 (VDD), U1.28 (VDD); also elsewhere on the board
/CHAVE1: U1.38 (SPP0/RD0); also elsewhere on the board
/CHAVE2: U1.39 (SPP1/RD1); also elsewhere on the board
/CHAVE3: U1.40 (SPP2/RD2); also elsewhere on the board
/CHAVE4: U1.41 (SPP3/RD3); also elsewhere on the board
/CHAVE5: U1.2 (SPP4/RD4); also elsewhere on the board
/DB4: U1.21 (RA2/AN2/Vref-/CVref); also elsewhere on the board
/DB5: U1.22 (RA3/AN3/Vref+); also elsewhere on the board
/DB6: U1.23 (RA4/T0CKI/C1OUT/RCV); also elsewhere on the board
/DB7: U1.24 (RA5/AN4/~SS/HLVDIN/C2OUT); also elsewhere on the board
/DIFERENCIAL1: U1.10 (RB2/AN8/INT2/VMO); also elsewhere on the board
/DIFERENCIAL2: U1.14 (RB4/AN11/KBI0/CSSPP); also elsewhere on the board
/EN: U1.20 (RA1/AN1); also elsewhere on the board
/PWM: U1.11 (RB3/AN9/CCP2/VPO); also elsewhere on the board
/RC4: U1.35 (~UOE/CCP2/T1OSI/RC1); also elsewhere on the board
/RC5: U1.36 (P1A/CCP1/RC2); also elsewhere on the board
/RS: U1.19 (RA0/AN0); also elsewhere on the board
/RX: U1.44 (TX/CK/RC6); also elsewhere on the board
/SCL: U1.9 (RB1/AN10/INT1/SCK/SCL); also elsewhere on the board
/SDA: U1.8 (RB0/AN12/INT0/FLT0/SDI/SDA); also elsewhere on the board
/TRIMPOT: U1.27 (OESPP/AN7/RE2); also elsewhere on the board
/TX: U1.1 (SDO/RX/DT/RC7); also elsewhere on the board
GND: C1.1, C2.1, C14.2, J1.4, SW1.3, U1.6 (VSS), U1.29 (VSS); also elsewhere on the board
ICCK: U1.12 ((ICCK/ICPGC)); also elsewhere on the board
ICDT: U1.13 ((ICDT/ICPGD)); also elsewhere on the board
ICPORTS: U1.34 ((ICPORTS)); also elsewhere on the board
ICRST: U1.33 ((~ICRST/ICVpp)); also elsewhere on the board
unnamed: C1.2, U1.31 (RA6/OSC2/CLKO), Y1.1
unnamed: C2.2, U1.30 (OSC1/CLKI), Y1.2
PGC: J1.2, U1.16 (RB6/KBI2/PGC)
PGD: J1.3, U1.17 (RB7/KBI3/PGD)
RB5: U1.15 (RB5/KBI1/PGM); also elsewhere on the board
RC0: U1.32 (T1OSO/T13CKI/RC0); also elsewhere on the board
RD5: U1.3 (P1B/SPP5/RD5); also elsewhere on the board
RD6: U1.4 (P1C/SPP6/RD6); also elsewhere on the board
RD7: U1.5 (P1D/SPP7/RD7); also elsewhere on the board
RE0: U1.25 (CK1SPP/AN5/RE0); also elsewhere on the board
RE1: U1.26 (CK2SPP/AN6/RE1); also elsewhere on the board
VPP: J1.6, R1.2, SW1.1, U1.18 (Vpp/~MCLR/RE3)
VUSB: U1.37 (VUSB); also elsewhere on the board

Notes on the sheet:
26/05/2021
Autores : Lucas Ferreira Machado João Roberto da Silva Couto André Luís Oliveira de Almeida
Esquema elétrico - PBLE01

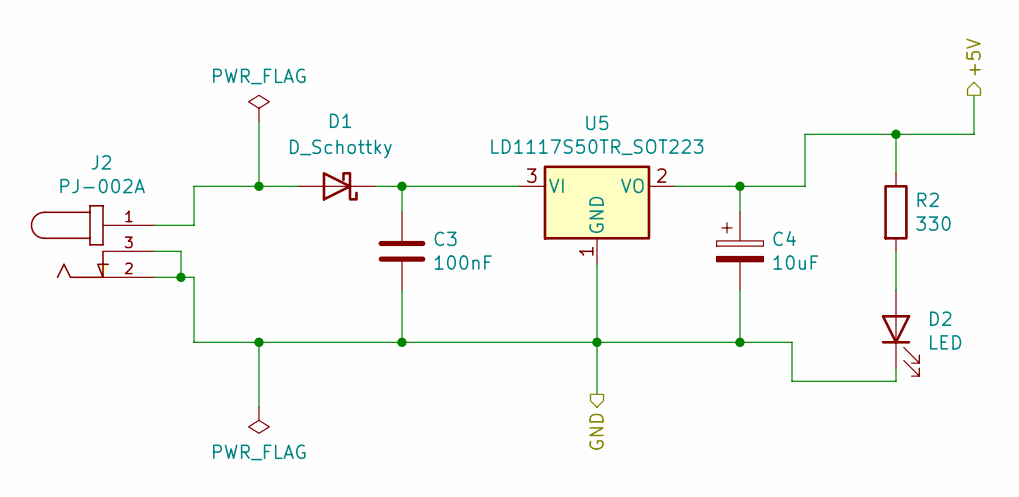
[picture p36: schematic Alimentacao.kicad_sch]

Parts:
C3: 100nF; C_0805_2012Metric_Pad1.18x1.45mm_HandSolder
C4: 10uF; CAPPM3216X180N
D1: D_Schottky; D_0603_1608Metric
D2: LED; LTST-C150GKT
J2: PJ-002A; CUI_PJ-002A
R2: 330; R_0805_2012Metric_Pad1.20x1.40mm_HandSolder
U5: LD1117S50TR_SOT223; TO-252-3_TabPin2

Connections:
+5V: C4.1, R2.1, U5.2 (VO); also elsewhere on the board
GND: C3.2, C4.2, D2.1 (K), J2.2, J2.3, U5.1 (GND); also elsewhere on the board
unnamed: C3.1, D1.1 (K), U5.3 (VI)
unnamed: D1.2 (A), J2.1
unnamed: D2.2 (A), R2.2

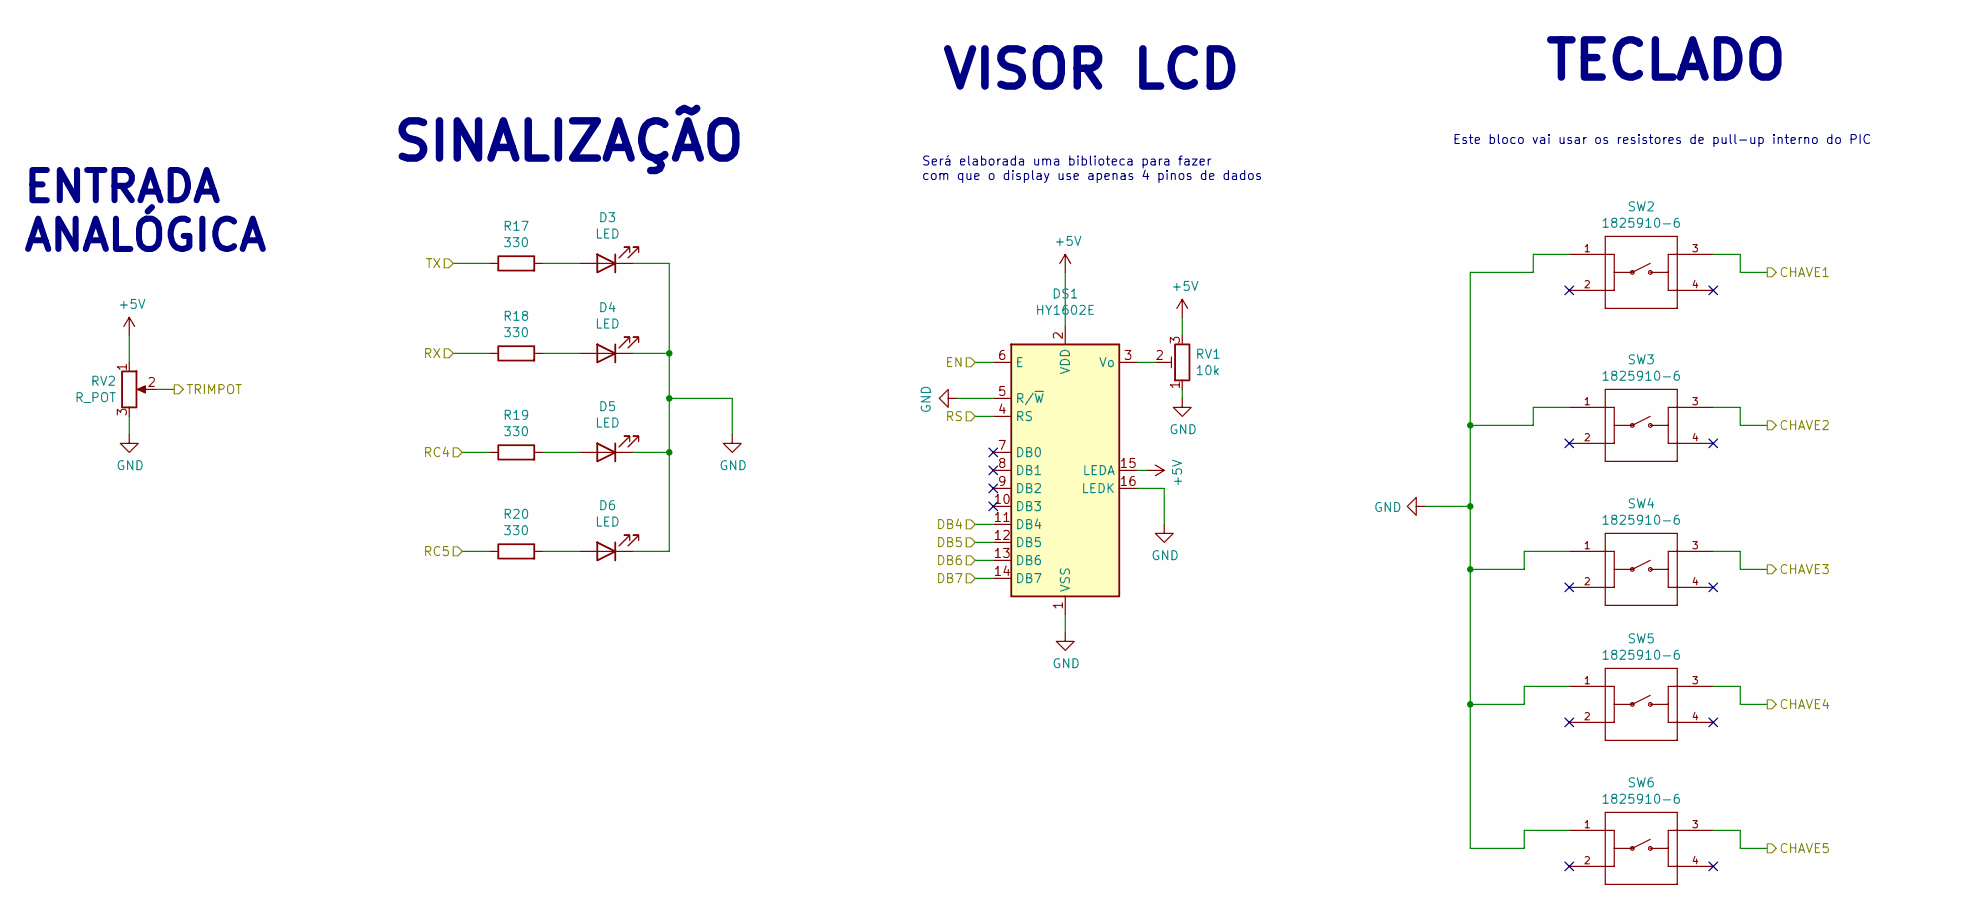
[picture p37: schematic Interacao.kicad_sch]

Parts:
D3, D4, D5, D6: LED; LTST-C150GKT
DS1: HY1602E
R17, R18, R19, R20: 330; R_0805_2012Metric_Pad1.20x1.40mm_HandSolder
RV1: 10k; Potentiometer_Bourns_3296W_Vertical
RV2: R_POT; P160KN0QC15B100K
SW2, SW3, SW4, SW5, SW6: 1825910-6; SW_1825910-6-4

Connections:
+5V: DS1.2 (VDD), DS1.15 (LEDA), RV1.3, RV2.1; also elsewhere on the board
/CHAVE1: SW6.3; also elsewhere on the board
/CHAVE2: SW5.3; also elsewhere on the board
/CHAVE3: SW4.3; also elsewhere on the board
/CHAVE4: SW3.3; also elsewhere on the board
/CHAVE5: SW2.3; also elsewhere on the board
/DB4: DS1.11 (DB4); also elsewhere on the board
/DB5: DS1.12 (DB5); also elsewhere on the board
/DB6: DS1.13 (DB6); also elsewhere on the board
/DB7: DS1.14 (DB7); also elsewhere on the board
/EN: DS1.6 (E); also elsewhere on the board
/RC4: R19.1; also elsewhere on the board
/RC5: R20.1; also elsewhere on the board
/RS: DS1.4 (RS); also elsewhere on the board
/RX: R18.1; also elsewhere on the board
/TRIMPOT: RV2.2; also elsewhere on the board
/TX: R17.1; also elsewhere on the board
GND: D3.1 (K), D4.1 (K), D5.1 (K), D6.1 (K), DS1.1 (VSS), DS1.5 (R/~W), DS1.16 (LEDK), RV1.1, RV2.3, SW2.1, SW3.1, SW4.1, SW5.1, SW6.1; also elsewhere on the board
unnamed: D3.2 (A), R17.2
unnamed: D4.2 (A), R18.2
unnamed: D5.2 (A), R19.2
unnamed: D6.2 (A), R20.2
unnamed: DS1.3 (Vo), RV1.2

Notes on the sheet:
Será elaborada uma biblioteca para fazer com que o display use apenas 4 pinos de dados
ENTRADA ANALÓGICA
TECLADO
Este bloco vai usar os resistores de pull-up interno do PIC
VISOR LCD
SINALIZAÇÃO

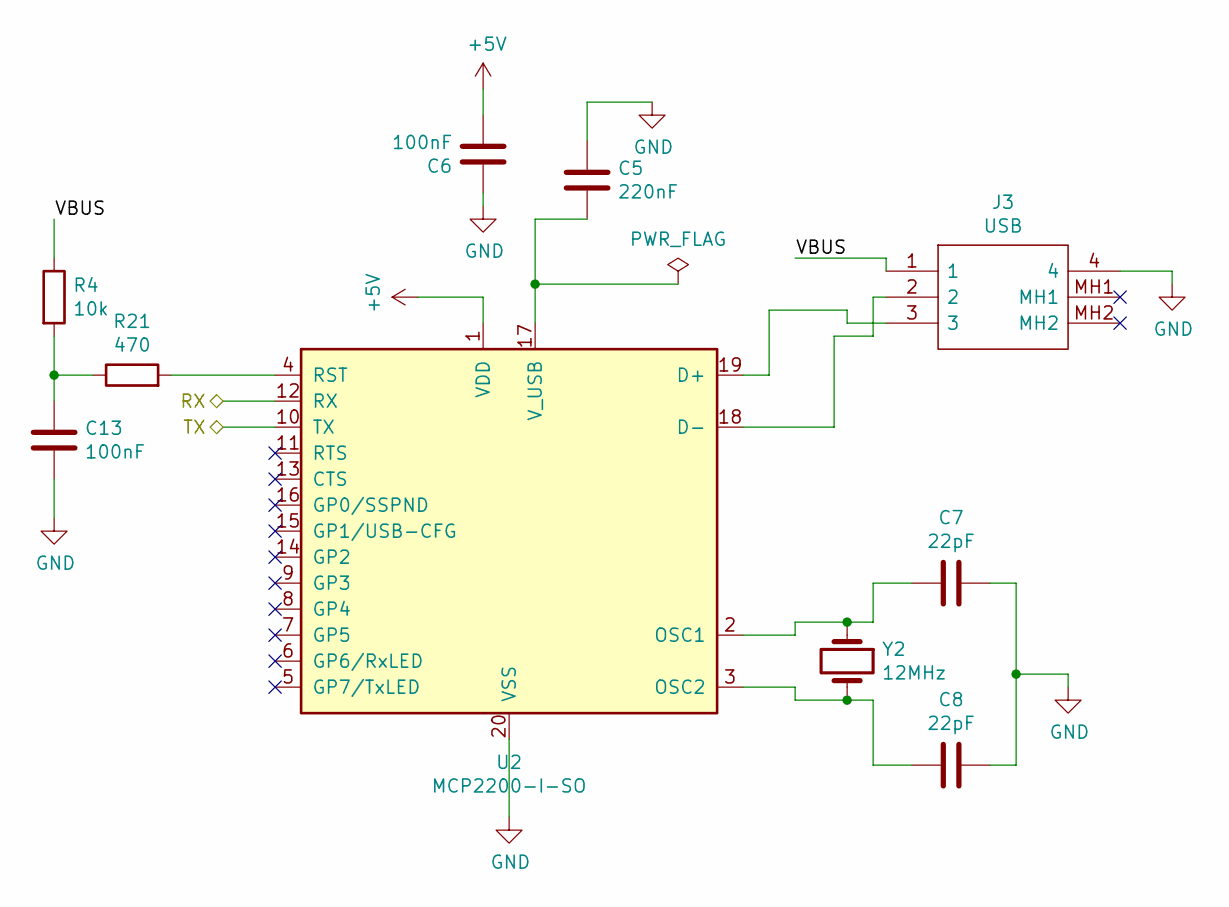
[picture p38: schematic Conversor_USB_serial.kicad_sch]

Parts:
C5: 220nF; C_0805_2012Metric_Pad1.18x1.45mm_HandSolder
C6, C13: 100nF; C_0805_2012Metric_Pad1.18x1.45mm_HandSolder
C7, C8: 22pF; C_0805_2012Metric_Pad1.18x1.45mm_HandSolder
J3: USB; 8974300490000000; Mouser Part Number 575-8974349
R4: 10k; R_0805_2012Metric_Pad1.20x1.40mm_HandSolder
R21: 470; R_0805_2012Metric_Pad1.20x1.40mm_HandSolder
U2: MCP2200-I-SO; SOIC-20W_7.5x12.8mm_P1.27mm
Y2: 12MHz; Crystal_HC49-4H_Vertical

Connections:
+5V: C6.2, U2.1 (VDD); also elsewhere on the board
/Comunicação serial /VBUS: J3.1, R4.1
/RX: U2.12 (RX); also elsewhere on the board
/TX: U2.10 (TX); also elsewhere on the board
GND: C5.1, C6.1, C7.1, C8.2, C13.2, J3.4, U2.20 (VSS); also elsewhere on the board
unnamed: C5.2, U2.17 (V_USB)
unnamed: C7.2, U2.2 (OSC1), Y2.1
unnamed: C8.1, U2.3 (OSC2), Y2.2
unnamed: C13.1, R4.2, R21.1
unnamed: J3.2, U2.18 (D-)
unnamed: J3.3, U2.19 (D+)
unnamed: R21.2, U2.4 (RST)

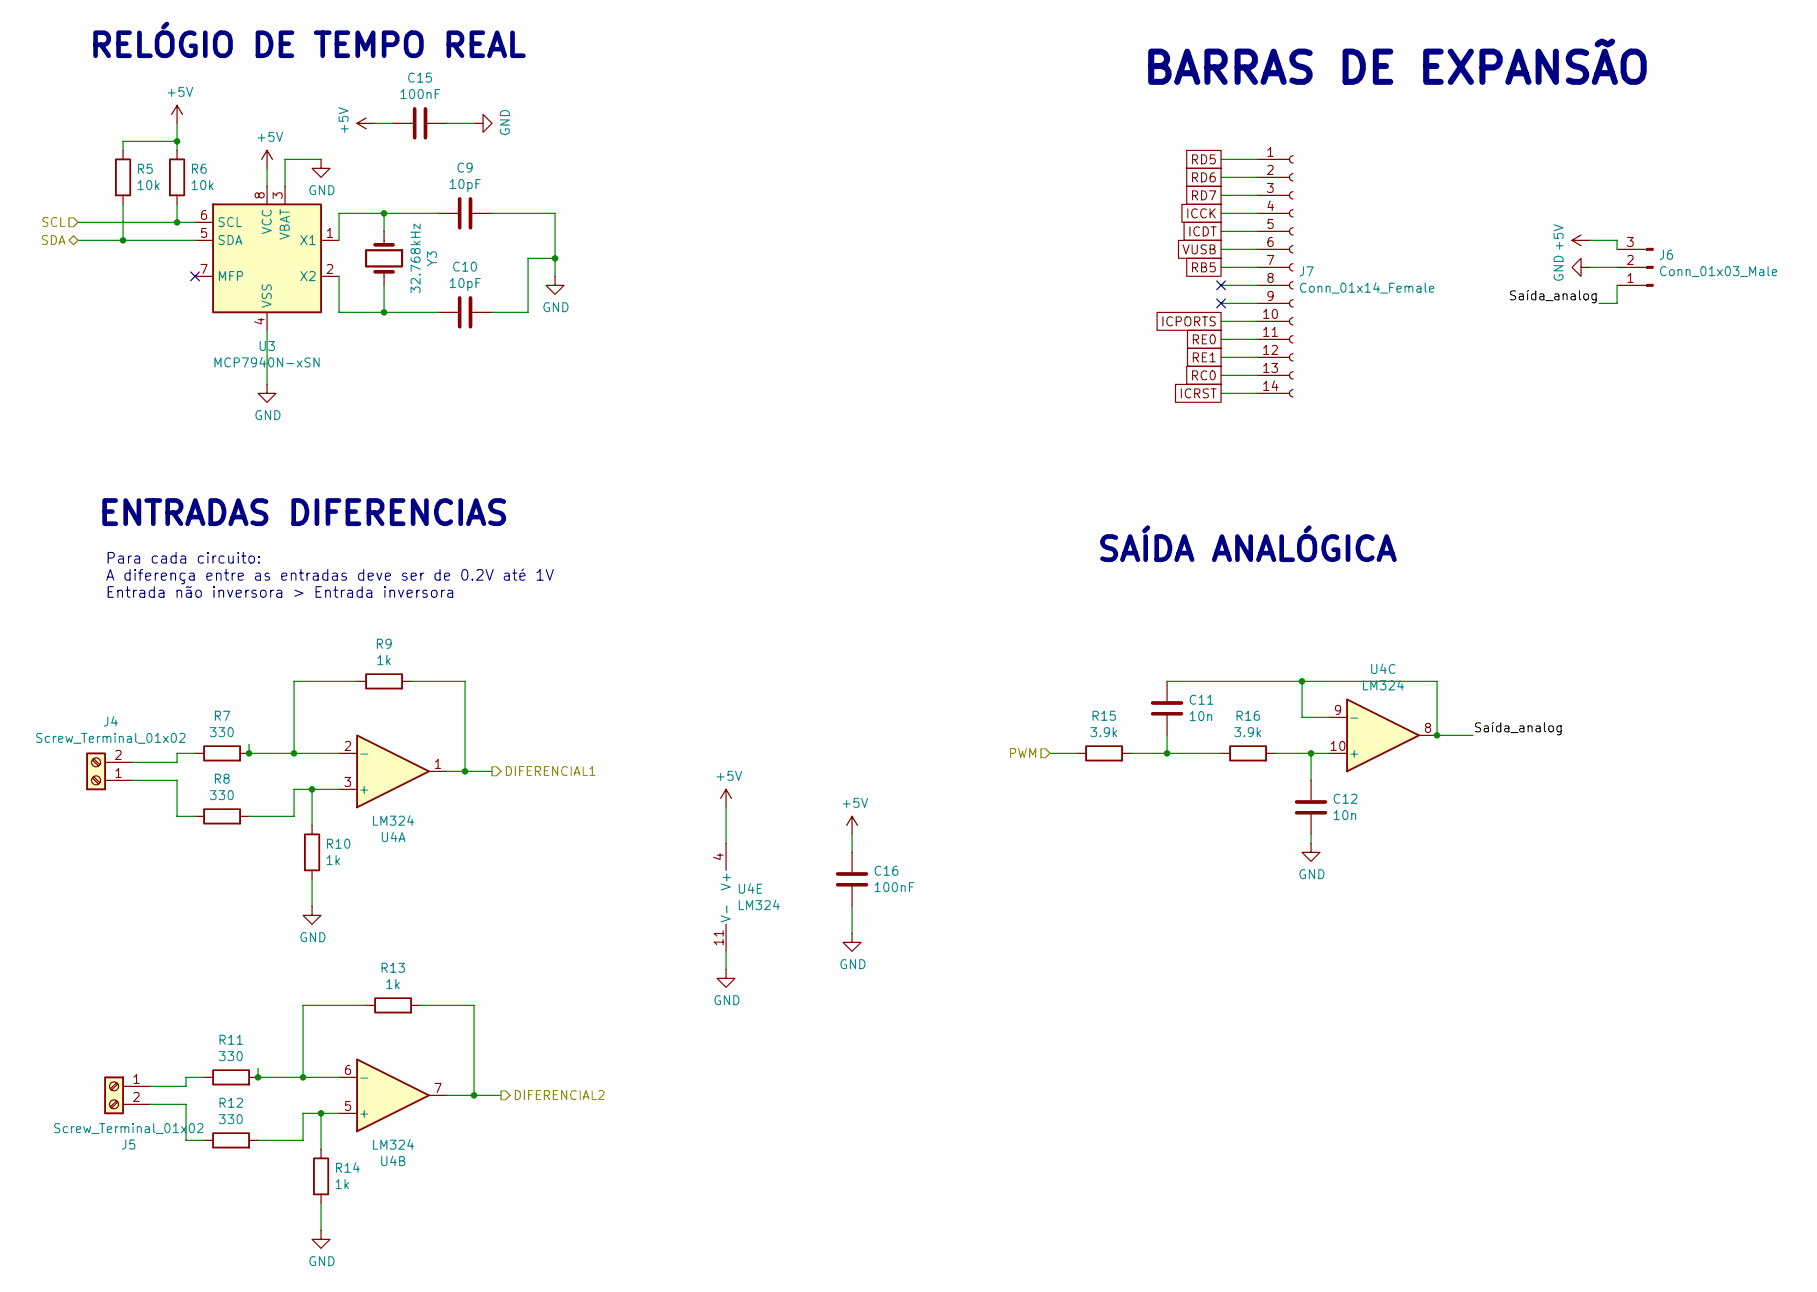
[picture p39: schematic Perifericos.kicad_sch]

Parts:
C9, C10: 10pF; C_0805_2012Metric_Pad1.18x1.45mm_HandSolder
C11, C12: 10n; C_0805_2012Metric_Pad1.18x1.45mm_HandSolder
C15, C16: 100nF; C_0805_2012Metric_Pad1.18x1.45mm_HandSolder
J4, J5: Screw_Terminal_01x02; TerminalBlock_MetzConnect_Type011_RT05502HBWC_1x02_P5.00mm_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
J6: Conn_01x03_Male; PinHeader_1x03_P2.54mm_Vertical
J7: Conn_01x14_Female; PinSocket_1x14_P2.54mm_Vertical
R5, R6: 10k; R_0805_2012Metric_Pad1.20x1.40mm_HandSolder
R7, R8, R11, R12: 330; R_0805_2012Metric_Pad1.20x1.40mm_HandSolder
R9, R10, R13, R14: 1k; R_0805_2012Metric_Pad1.20x1.40mm_HandSolder
R15, R16: 3.9k; R_0805_2012Metric_Pad1.20x1.40mm_HandSolder
U3: MCP7940N-xSN; SOIC127P600X175-8N
U4: LM324; SOIC127P600X175-14N
Y3: 32.768kHz; XTAL_AB38T-32.768KHZ

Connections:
+5V: C15.1, C16.1, J6.3, R5.1, R6.1, U3.8 (VCC), U4.4 (V+); also elsewhere on the board
/DIFERENCIAL1: R9.2, U4.1; also elsewhere on the board
/DIFERENCIAL2: R13.2, U4.7; also elsewhere on the board
/PWM: R15.1; also elsewhere on the board
/Periféricos/Saída_analog: C11.1, J6.1, U4.8, U4.9 (-)
/SCL: R6.2, U3.6 (SCL); also elsewhere on the board
/SDA: R5.2, U3.5 (SDA); also elsewhere on the board
GND: C9.1, C10.2, C12.2, C15.2, C16.2, J6.2, R10.2, R14.2, U3.3 (VBAT), U3.4 (VSS), U4.11 (V-); also elsewhere on the board
ICCK: J7.4; also elsewhere on the board
ICDT: J7.5; also elsewhere on the board
ICPORTS: J7.10; also elsewhere on the board
ICRST: J7.14; also elsewhere on the board
unnamed: C9.2, U3.1 (X1), Y3.1
unnamed: C10.1, U3.2 (X2), Y3.2
unnamed: C11.2, R15.2, R16.1
unnamed: C12.1, R16.2, U4.10 (+)
unnamed: J4.1, R8.1
unnamed: J4.2, R7.1
unnamed: J5.1, R11.1
unnamed: J5.2, R12.1
unnamed: R7.2, R9.1, U4.2 (-)
unnamed: R8.2, R10.1, U4.3 (+)
unnamed: R11.2, R13.1, U4.6 (-)
unnamed: R12.2, R14.1, U4.5 (+)
RB5: J7.7; also elsewhere on the board
RC0: J7.13; also elsewhere on the board
RD5: J7.1; also elsewhere on the board
RD6: J7.2; also elsewhere on the board
RD7: J7.3; also elsewhere on the board
RE0: J7.11; also elsewhere on the board
RE1: J7.12; also elsewhere on the board
VUSB: J7.6; also elsewhere on the board

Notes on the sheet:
ENTRADAS DIFERENCIAS
BARRAS DE EXPANSÃO
RELÓGIO DE TEMPO REAL
SAÍDA ANALÓGICA
Para cada circuito: A diferença entre as entradas deve ser de 0.2V até 1V Entrada não inversora > Entrada inversora

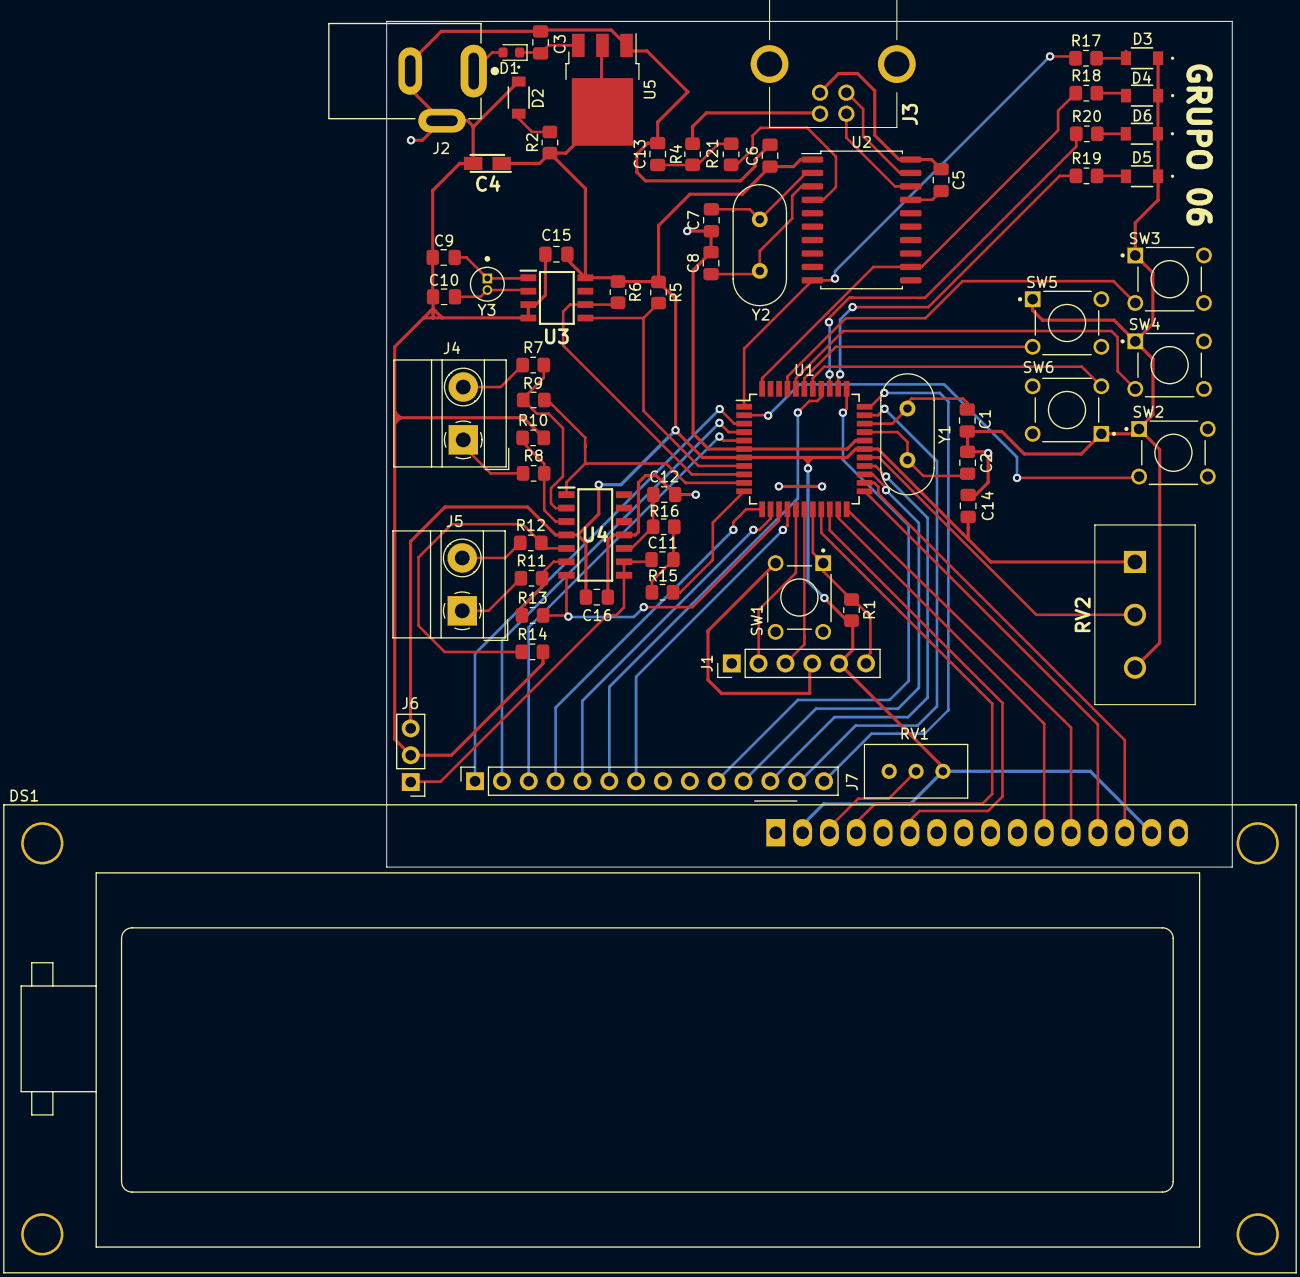
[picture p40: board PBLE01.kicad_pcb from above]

Board: 2 copper layers, 80.0 x 80.0 mm, 66 parts (0 on the bottom side), 69 nets.

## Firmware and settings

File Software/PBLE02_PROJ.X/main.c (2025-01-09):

#include "config.h"
#include "pic18f4520.h"
#include "pwm.h"
#include "timer.h"
#include "adc.h"
#include "lcd.h"
#include "keypad.h"
#include "event.h"
#include "var.h"
#include "stateMachine.h"
#include "output.h"
#include "rtc.h"
#include "led.h"

void main(void) {
     
    kpInit();
    lcdInit();
    timerInit();
    varInit();
    eventInit();
    adcInit();
    dsInit();
    ledInit();
    for (;;) {
        timerReset(1500);
       
        smLoop();
        
        timerWait();
    }
}

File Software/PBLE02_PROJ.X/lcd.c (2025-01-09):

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

#include "lcd.h"
#include "bits.h"
#include "serial.h"
#include <pic18f4550.h>
//portd
#define RS 0
#define EN 1
//portB
#define DB4 2 
#define DB5 3
#define DB6 4
#define DB7 5

void Delay40us(void) {
    unsigned char j;
    for (j = 0; j < 68; j++);
}

void Delay2ms(void) {
    unsigned char j, k;
    for (j = 0; j < 20; j++)
        for (k = 0; k < 178; k++);
}

void pulseEnable() {
    PORTAbits.RA1 = 1;
    PORTAbits.RA1 = 0;
}

void lcdCommand4bits(unsigned char cmd, unsigned char data) {
   
    if(data){
        PORTAbits.RA0 = 1;
    }else{
        PORTAbits.RA0 = 0;
    }
    
    
    if (bitTst(cmd, 7)) {
        PORTAbits.RA5 = 1;
    } else {
        PORTAbits.RA5 = 0;
    }


    if (bitTst(cmd, 6)) {
        PORTAbits.RA4 = 1;
    } else {
        PORTAbits.RA4 = 0;
    }


    if (bitTst(cmd, 5)) {
        PORTAbits.RA3 = 1;
    } else {
        PORTAbits.RA3 = 0;
    }


    if (bitTst(cmd, 4)) {
        PORTAbits.RA2 = 1;
    } else {
        PORTAbits.RA2 = 0;
    }

    pulseEnable();
}

void lcdCommand(unsigned char cmd) {
    lcdCommand4bits(cmd, 0);
    lcdCommand4bits(cmd << 4, 0);


    if ((cmd == 0x02) || (cmd == 0x01)) {
        Delay2ms();
    } else {
        Delay40us();
    }
}

void lcdData(unsigned char valor) {
    lcdCommand4bits(valor, 1);
    lcdCommand4bits(valor << 4, 1);    
    Delay40us();

}

void lcdInt(int val) {
    //lcdData((val / 10000) % 10 + 48);
    //lcdData((val / 1000) % 10 + 48);
    lcdData((val / 100) % 10 + 48);
    lcdData((val / 10) % 10 + 48);
    lcdData((val / 1) % 10 + 48);
}

void lcdString(char msg[]) {
    int i = 0;
	while (msg[i] != 0) {
		lcdData(msg[i]);
		i++;
	}
}

void lcdPosition(int line, int col) {
	if (line == 0) {
		lcdCommand(0x80 + (col % 16));
	}
	if (line == 1) {
		lcdCommand(0xC0 + (col % 16));
	}
}

void lcdInit(void) {
    unsigned char i;
    // configura??es de dire??o dos terminais
    TRISA = 0x00;   
    bitClr(SPPCFG, 5);
    ADCON1 = 0b00001111; //apenas

    
    PORTAbits.RA0 = 0;
    // garante inicializa??o do LCD (+-15ms)
    for (i = 0; i < 7; i++)
        Delay2ms();

    //precisa enviar 4x pra garantir 8 bits
    lcdCommand4bits(0x30, 0); //8bits, 2 linhas, 5x8
    Delay2ms();

    lcdCommand4bits(0x30, 0); //8bits, 2 linhas, 5x8
    Delay2ms();

    lcdCommand4bits(0x30, 0); //8bits, 2 linhas, 5x8
    Delay2ms();

    lcdCommand4bits(0x20, 0); //4bits
    Delay2ms();

    lcdCommand(0x28); //4bits
    lcdCommand(0x06); //modo incremental
    lcdCommand(0x0F); //display e cursor on, com blink
    lcdCommand(0x01); //limpar display
}

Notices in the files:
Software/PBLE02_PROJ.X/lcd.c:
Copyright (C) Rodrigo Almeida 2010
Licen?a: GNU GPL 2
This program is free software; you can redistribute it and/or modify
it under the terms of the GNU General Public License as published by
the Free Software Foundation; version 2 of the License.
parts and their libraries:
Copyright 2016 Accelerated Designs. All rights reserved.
